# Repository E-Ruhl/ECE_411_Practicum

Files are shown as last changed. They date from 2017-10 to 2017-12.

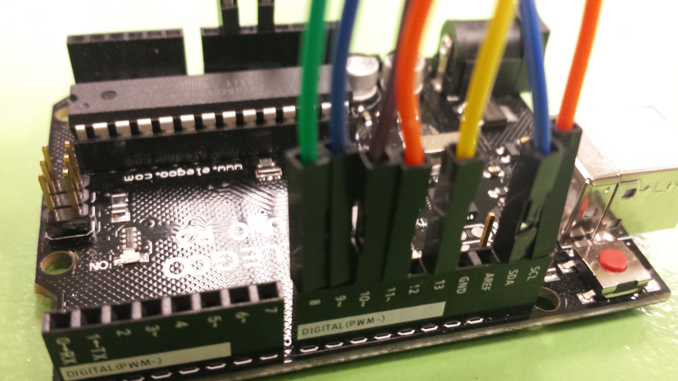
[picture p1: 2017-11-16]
Photo Documentation/Prototype Board Wiring.jpg

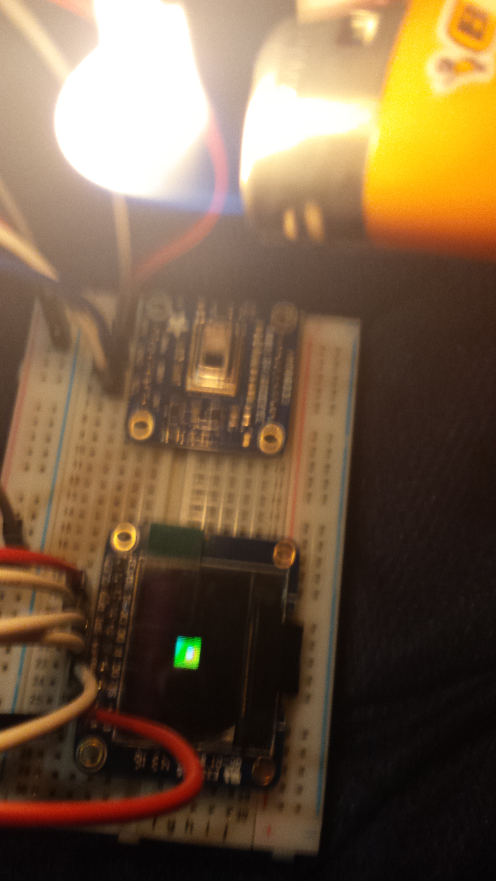
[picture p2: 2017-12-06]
Photo Documentation/Testing_Prototype.jpg

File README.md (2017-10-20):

# ECE_411_Practicum
Project development

Check out these sites for getting an idea of what we might try

https://www.adafruit.com/product/3538
this is the IR Camera

https://www.adafruit.com/product/684
this is the OLED screen

http://www.microchip.com/wwwproducts/en/ATmega328
this is the microcontroller

http://www.instructables.com/id/Arduino-Data-Glasses-for-My-Multimeter/
This is an instructable for a DIY Heads up display that actually has decent documentation

https://www.autodesk.com/education/free-software/eagle#
You'll need to go here to download the educational version of Eagle Cad

Also because I got super excited and already ordered most of the material for the thermal overlay augmented reality HUD, if you're into that idea (because I'm eventually doing it either way) then read up on Bicubic interpolation!!!

Other programs you might want to consider
Jupyter Notebook- Allows you to use basic Latex markdown and run python in an online application.

https://wwwspikenzielabs.com/Catalog/index.php?main_page=product_infor&products_id=614

We'll set up meeting notes on friday.

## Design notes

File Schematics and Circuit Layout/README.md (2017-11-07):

Folder containing all the information related to the schematics needed to build the Thermal Imaging HUD

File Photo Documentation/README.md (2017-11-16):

This is where the various project photos are stored. The photo documentation was taken from 1st prototype to final production.

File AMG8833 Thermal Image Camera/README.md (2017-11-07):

Folder containing all information related to the AMG8833 Thermal Image Camera

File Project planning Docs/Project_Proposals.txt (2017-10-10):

"Bucket of Options"

1. Light-up frisbee
2. Talking ball
3. Pasive aggressive condiment robot
4. Thermal overlay augmented reality hub
5. Visual distance to audio converter (Vision impared assistant device)
6. Chat bot
7. Kegorator
8. LED tesseract
9. Path finder robot
10. Amature band jammer

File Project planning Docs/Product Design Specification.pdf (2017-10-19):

# Thermal Imaging HUD

Eric Ruhl
Preston Cazier
Kirk Hooper
Dustin Schnelle

Version 1.1 10/17/17

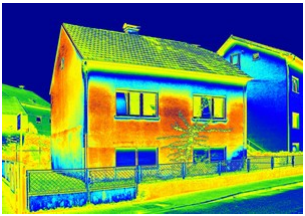
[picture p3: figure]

### Table of Contents

Product Proposal | Page 3-4
Product Description | Page 3
Requirements | Page 4
Deliverables | Page 4
Product Design Specifications | Page 5-6
Needs | Page 5
Objectives | Page 5
Background | Page 5
Marketing Requirements | Page 5
Constraints | Page 6
Engineering Requirements | Page 6
Functionality | Page 6
Performance | Page 6
Economic | Page 6
Energy | Page 6
Environmental | Page 6
Health and Safety | Page 6
Legal | Page 6
Maintainability | Page 6
Manufacturability | Page 6
Operational | Page 6
Political | Page 6
Reliability and Availability | Page 6
Social and Cultural | Page 6
Usability | Page 6

### Project Proposal

Project Description:
Our team is going to build a thermal imaging device. Our device will use a sensor to obtain a thermal image of the environment and an actuator to display the thermal image. Then we will use lenses to create a virtual image of the thermal image. The device should be able to take a thermal image produced by the sensor and then increase the resolution of the image before being displayed to the actuator.

Our first idea is to create a thermal image using a thermal imaging camera. The thermal imaging camera will transmit the data to a processor where it will preform the task of increasing the resolution of the image before displaying it to an LED display. We want the design to be compact, so it can be worn by the user in the form of glasses. At this point we are still trying to figure out the exact method that we need to use in order to increase the resolution of the image without requiring too much storage space.

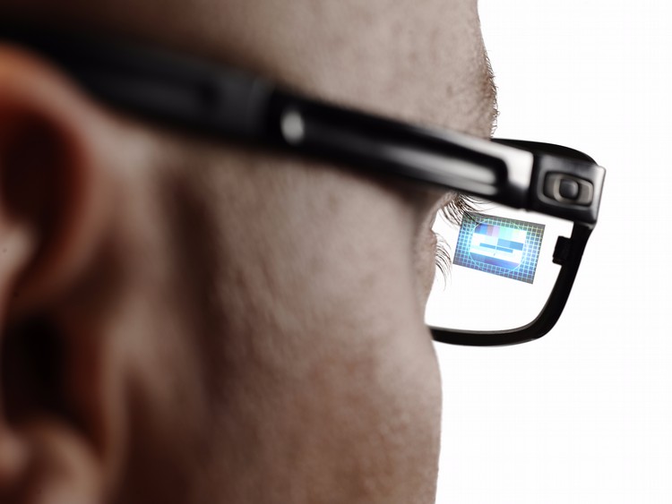
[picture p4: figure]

Image #1: Example of the virtual image display

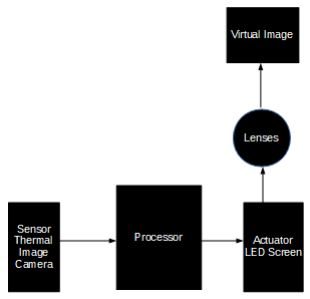
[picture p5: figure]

Image #2: Basic dataflow of the Thermal Imaging HUD

Requirements:
- The device must be able to product a real-time thermal image of the environment.
- The device must be compact enough, so that it can be worn in the form of glasses.
- The resolution must be clear enough to analyze the thermal image.

Deliverables:
- One working prototype of a thermal imaging HUD.

### Product Design Specifications

Needs:
Our team has decided to create a device that will display thermal images in real-time for our ECE-411 practicum project. In order to produce a thermal image we will use a thermal imaging camera. Thermal imaging cameras are devices that translate thermal energy into images that can be displayed and analyzed. Thermal imaging technology is currently being used by the military, firefighters, law enforcement, and technicians to name just a few. As most thermal imaging technology costs upwards of $500 our groups' mission is to try to create a thermal imaging device that will be low cost compared to what's currently on the market. This device would be useful for anyone that wants to build a thermal imaging device on a budget. It could be used for fun or tackling problems that involve thermal energy. We believe that we will be successful because of our teams' various engineering backgrounds. Ideally, this project will help us achieve a good grade in this class, look great on a resume and allow us to gain valuable team project development skills. Although we are taking on the risk of failing the class if unsuccessful. The cost will be affordable for a student and be able to be completed in one term (~ 10 weeks). Obtaining a working prototype with a thermal camera, OLED screen, and microprocessor will be our “midterm” and a fully functional final project will be our “final” for the class.

Objectives:
Our objective is to create a thermal imaging device using a thermal imaging camera and screen to display the thermal image. This will be a hands-free device that will display the thermal image to the user of the device as a virtual image. The device will receive input from a thermal camera produced by a thermal image. The thermal image will be processed by the processor in order to increase the resolution of the image and then be outputted to a screen. The screen will produce the image in order for glass lenses to create a virtual image. The device will be portable and compact so the user can wear them as glasses.

Background:
All of the other similar products on the market are more expensive; costing upwards of $500. Many of the devices are expensive because they're used in situations that require extreme reliability. Our device won't require that kind of reliability which allows for the device to be less expensive. This allows for our device to be used by hobbyist on a budget.

Marketing Requirements:
- The device should be compact enough so it can be worn as glasses.
- The device should process the thermal image fast enough to produce a video feed.
- The device should respond to the environment and changes in the environment.
- The device should be cheap to build.
- The device shouldn't cause harm to the user.
- The device should be simple to use.

Constraints:
- Must have at least one input sensor.
- Must have at least one output actuator.
- Must have some kind of digital or analog processor.
- Must have the microprocessor located on the PCB.
- Must be able to fit on a two-layer PCB.
- Must have documentation and use version control.
- Must be published with MIT license.

Engineering Requirements:
Functionality
The device need to refresh an image at a minimum of 10 Hz.
The image need to be viewable from a heads-up lens that is 1 sq. inch. Performance
The thermal images need to be recognizable from the heads-up display. Economic
Total parts cost will not exceed $200.
Energy
The device should be able to operate from a battery for at least 2 hours. Environmental
At least 50% of the devices modular components will be able to be replaced. Health and Safety
The device shouldn't become hotter than 75o
F.
Legal
The project will use a MIT license.
Maintain 10 Hz or less for the thermal camera (export requirement). Maintainability
Both the actuator and sensor should be easily replaceable on daughter boards. Manufacturability
PCB should be greater than 2 sq. inches and less than 20 sq. inches.
All the casing for the project will be commercially source-able.
Operational
The device needs to weigh between 1 lb and 5 lbs.
The device should be no more than 100 sq. inches total.
Reliability and Availability
The device should be able to detect thermal images between 1 ft to 20 ft. Usability
The device can be used in a mobile capacity.

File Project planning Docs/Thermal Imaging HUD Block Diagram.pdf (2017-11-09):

## Thermal Imaging HUD

## Block Diagram

Dustin Schnelle
Eric Rulh
Preston Cazier
Kirk Hooper

Table of Content:

Thermal Imaging HUD: Level 0 | Page 3
Thermal Imaging HUD: Level 1 | Page 4
Over Charge Protection: Level 0 | Page 5
LiPo Battery: Level 0 | Page 6
Brown Out/Over Discharge Protection: Level 0 | Page 7
3.3V Linear Regulation: Level 0 | Page 8
3.3V Linear Regulator: Level 0 | Page 9
Noise Reduction: Level 0 | Page 10
Oscillator: Level 0 | Page 11
Microcontroller: Level 0 | Page 12
AMG8833 Thermal Imaging Camera: Level 0 | Page 13
AMG8833 Thermal Imaging Camera: Level 1 | Page 14
Panasonic Infrared Sensor Array: Level 0 | Page 15
Linear Voltage Regulator AMG8833: Level 0 | Page 16
Level Shifting: Level 0 | Page 17
SSD1331 OLED Display: Level 0 | Page 18
SSD1331 OLED Display: Level 1 | Page 19
Linear Voltage Regulator SSD1331: Level 0 | Page 20
Non-Inverting High-to-Low Level Shifter: Level 0 | Page 21
OLED LCD Display: Level 0 | Page 22

Thermal Imaging HUD: Level 0

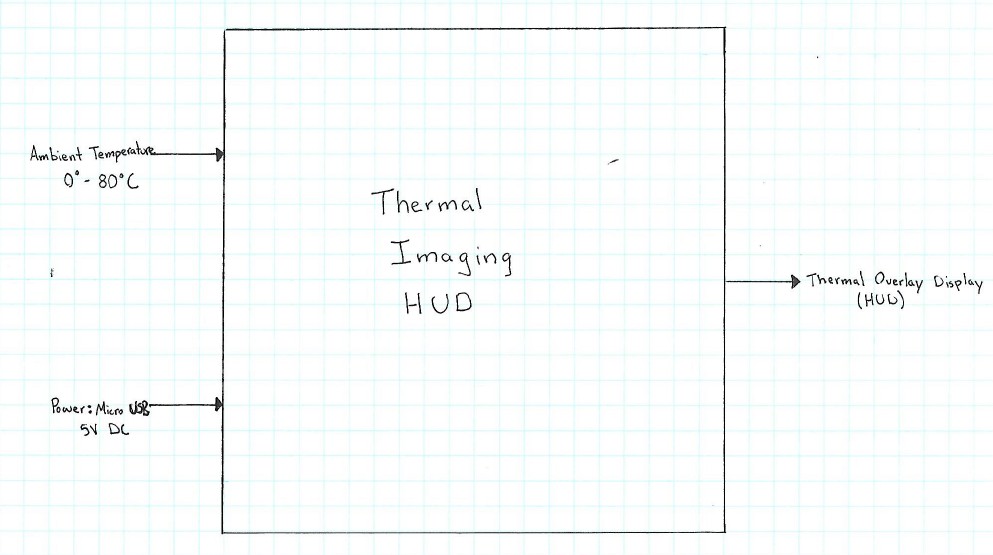
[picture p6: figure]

Module | Thermal Imaging HUD
Inputs | • Ambient temperature between 0o – 80oC • Power: Micro-USB 5V DC
Outputs | • Thermal Overlay Displays (HUD)
Functionality | Measure a matrix of ambient temperature between 0o – 80oC with an accuracy of +/-2.5oC. Then process the ambient temperature data and transmit via I2C communication. The microcontroller executes an image processing algorithm to extrapolate to a large more displayable matrix. Then transfer the data via SPI communication to the OLED display. The image is then optically transmitted through a glass lenses to the heads up display.

Thermal Imaging HUD: Level 1

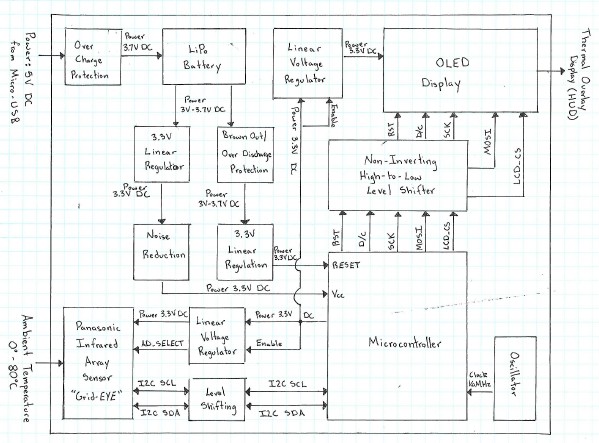
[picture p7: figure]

Over Charge Protection: Level 0

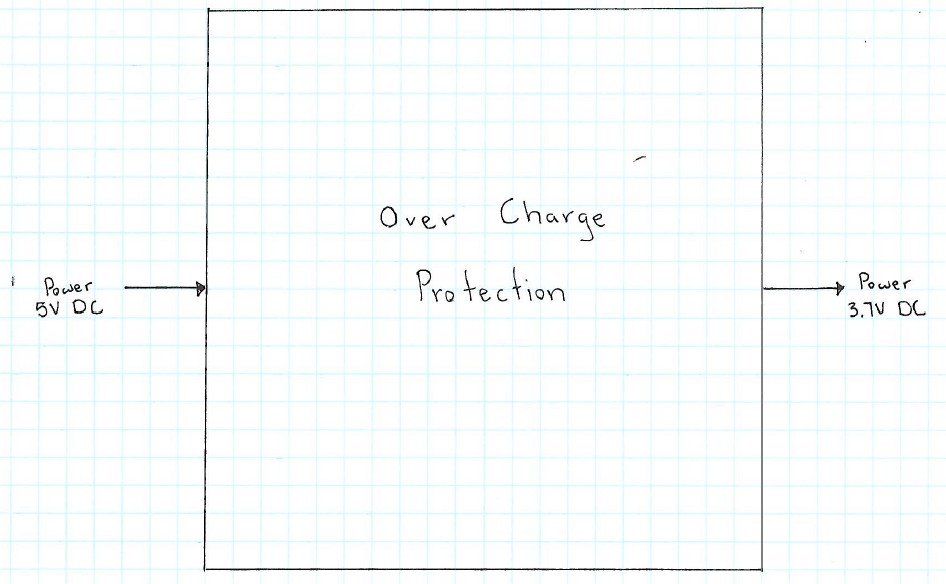
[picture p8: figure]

Module | Over Charge Protection
Inputs | • Power: 5V DC from the micro-USB
Outputs | • Power: 3.7V DC
Functionality | To prevent the LiPo battery from charging more than 3.7V DC. Prevent the explosion/damage of the LiPo battery.

LiPo Battery: Level 0

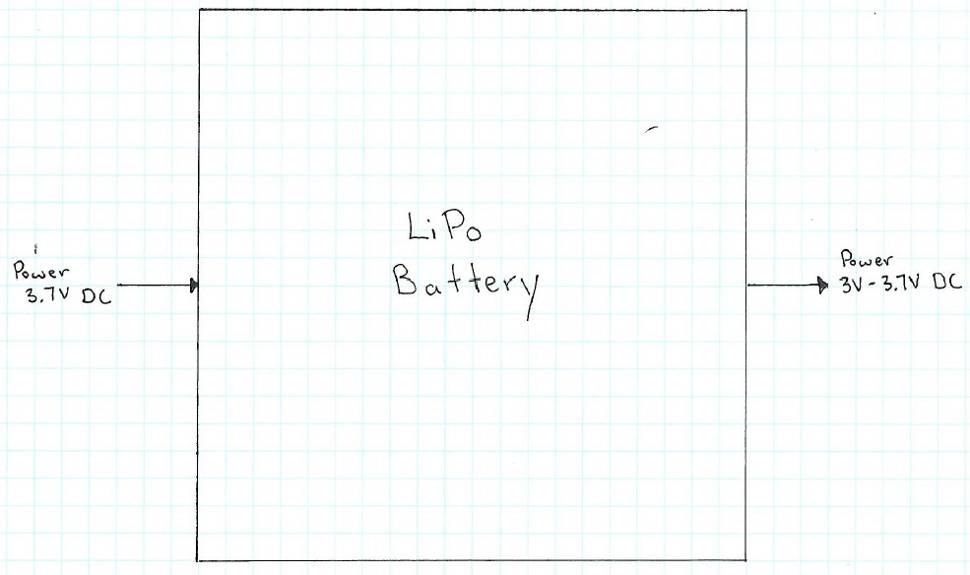
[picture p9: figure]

Module | LiPo Battery
Inputs | • Power: 3.7V DC from the over charge protection
Outputs | • Power: 3V – 3.7V DC
Functionality | To provide portable power to the circuit

Brown Out/Over Discharge Protection: Level 0

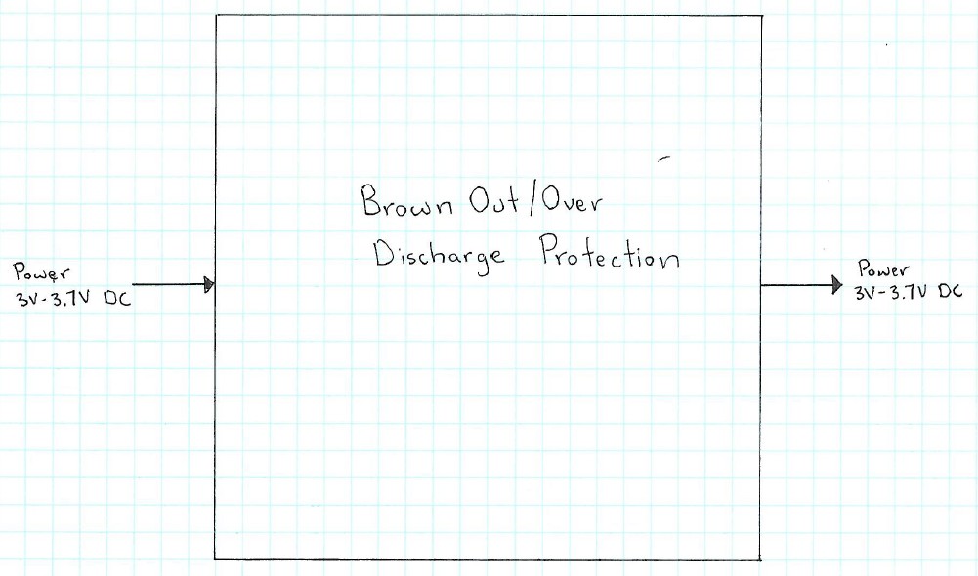
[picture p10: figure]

Module | Brown Out/Over Discharge Protection
Inputs | • Power: 3V – 3.7V DC from the LiPo battery
Outputs | • Power: 3V – 3.7V DC with undercurrent protection
Functionality | To protect the LiOp battery form over discharging.

3.3V Linear Regulation: Level 0

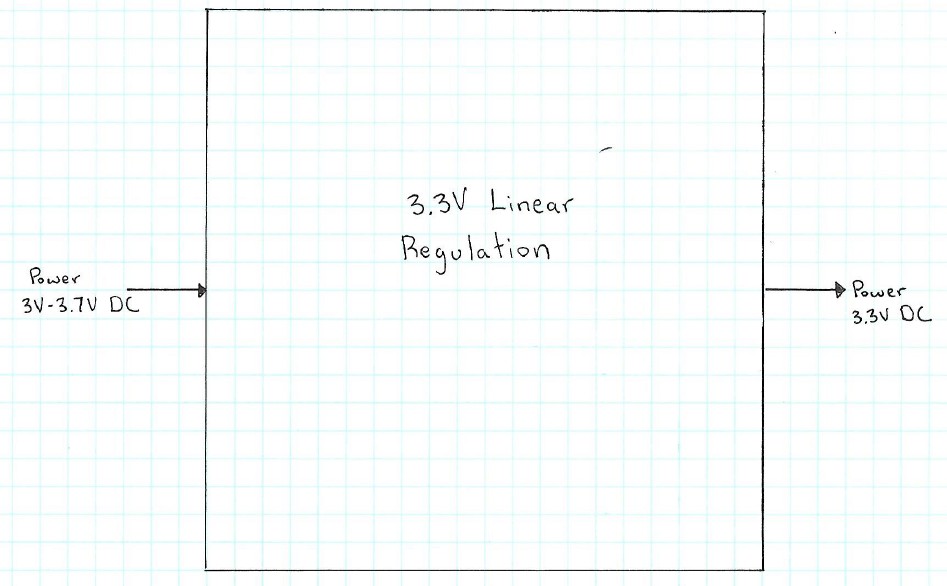
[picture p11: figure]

Module | 3.3V Linear Regulation
Inputs | • Power: 3V – 3.7V DC from LiPo battery through the brown out/over discharge protection.
Outputs | • Power: 3.3V DC
Functionality | Takes the voltage provided by the LiPo battery to provide a 3.3V DC Reset logic of the mircocontroller.

3.3V Linear Regulator: Level 0

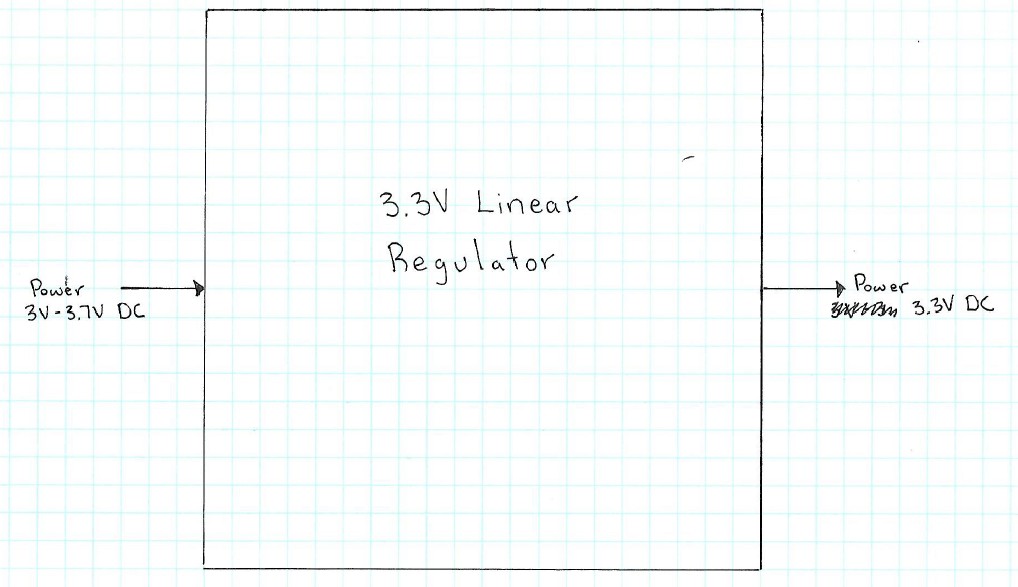
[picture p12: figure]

Module | 3.3V Linear Regulator
Inputs | • Power: 3V – 3.7V DC from the LiPo battery
Outputs | • Power: 3.3V DC
Functionality | Takes the voltage provided by the LiPo battery to provide a 3.3V DC Vcc for the mircocontroller.

Noise Reduction: Level 0

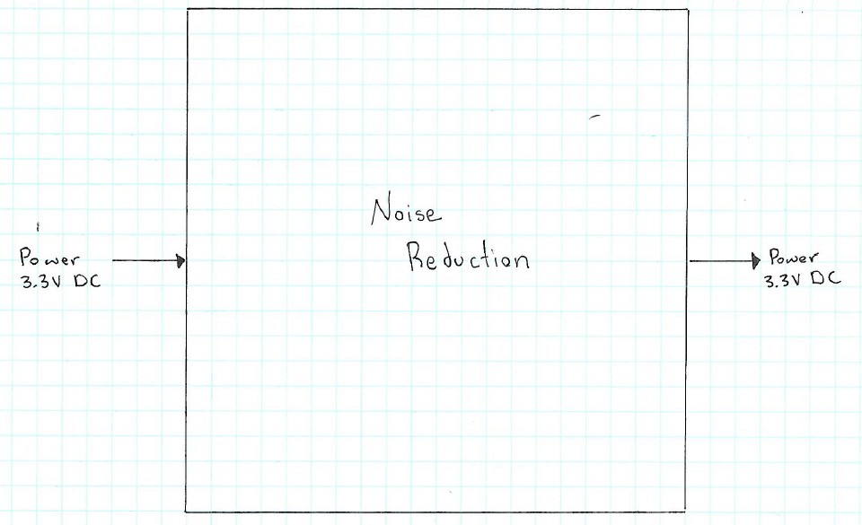
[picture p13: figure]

Module | Noise Reduction
Inputs | • Power: 3.3V DC from the voltage regulator
Outputs | • Power: 3.3V DC less noise
Functionality | Reducing electric noise from the ground plan using ferrite beads

Oscillator: Level 0

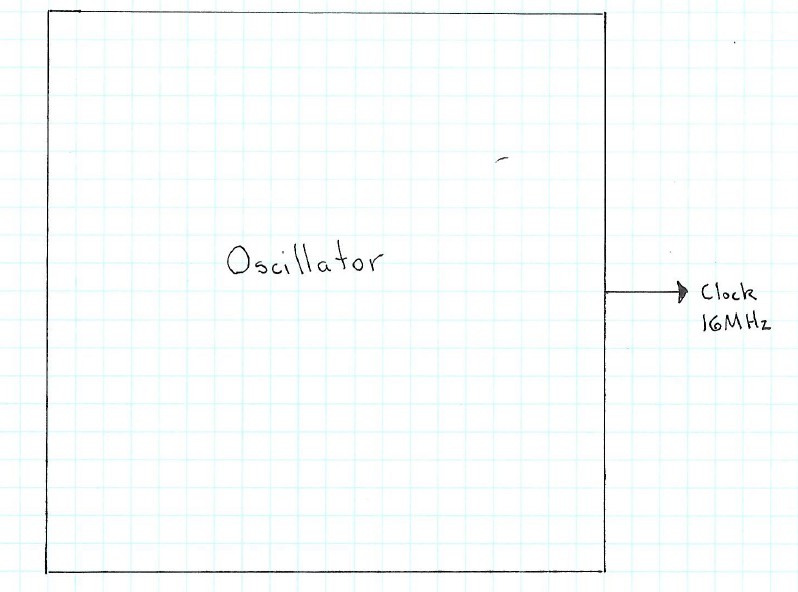
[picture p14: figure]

Module | Oscillator
Inputs | • None
Outputs | • Clock: 16MHz
Functionality | Sends the mircocontroller a 16MHz clock pulse.

Microcontroller: Level 0

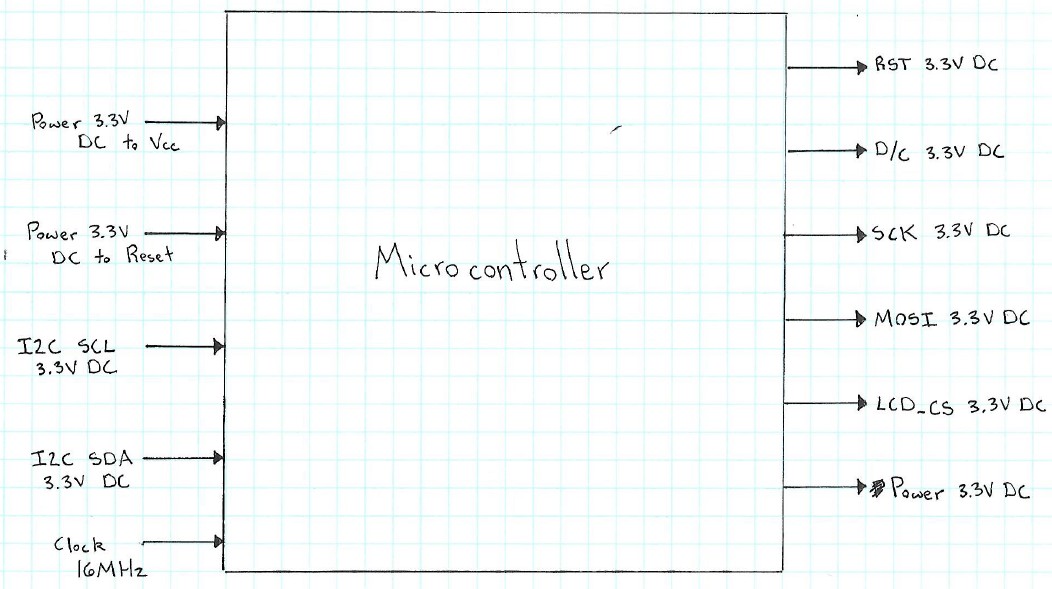
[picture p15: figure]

Module | Microcontroller
Inputs | • Power: 3.3V DC to Vcc and AVcc • Power: 3.3V DC to reset and once the voltage falls below 3.3V reset becomes active • I2C SCL: I2C serial clock line 3.3V DC bidirectional communication • I2C SDA: I2C serial data line 3.3V DC bidirectional communication • Clock: 16Mhz
Outputs | • Power: 3.3V DC • RST: 3.3V DC signal used to reset OLED display • D/C: 3.3V DC • SCK: 3.3V DC SPI clock line • MOSI: 3.3V DC SPI master out/slave in • LCD_CS: 3.3V DC signal to select the OLED display
Functionality | Translate the I2C data to SPI output data with an intermediate step of extrapolating the input 8x8 image matrix to a larger output image matrix.

AMG8833 Infrared Thermal Imaging Camera: Level 0

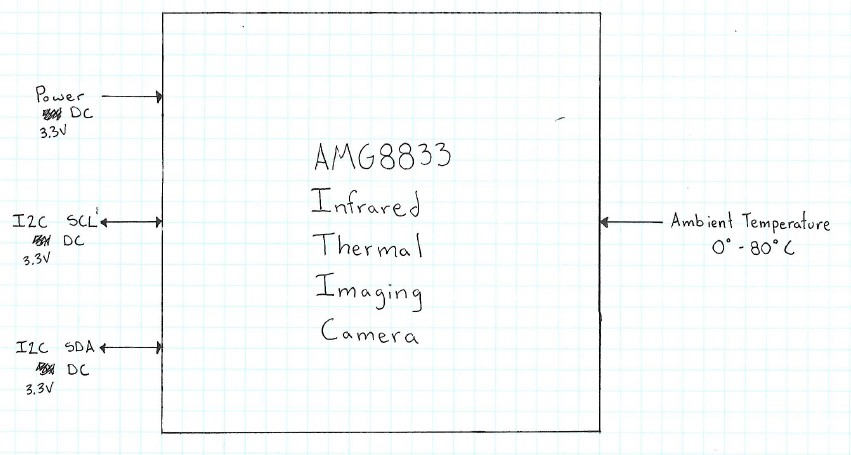
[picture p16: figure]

Module | AMG8833
Inputs | • Ambient temperature from 0o to 80oC • I2C SCL: to receive master requests • I2C SDA: to receive master requests • Power: 3.3V DC
Outputs | • I2C SCL: to transmit ambient temperature to master • I2C SDA: to transmit ambient temperature to master
Functionality | Return an array of 64 (8x8) individual infrared temperature readings with an accuracy of +/- 2.5oC via I2C when requested by master device.

AMG8833 Infrared Thermal Imaging Camera: Level 1

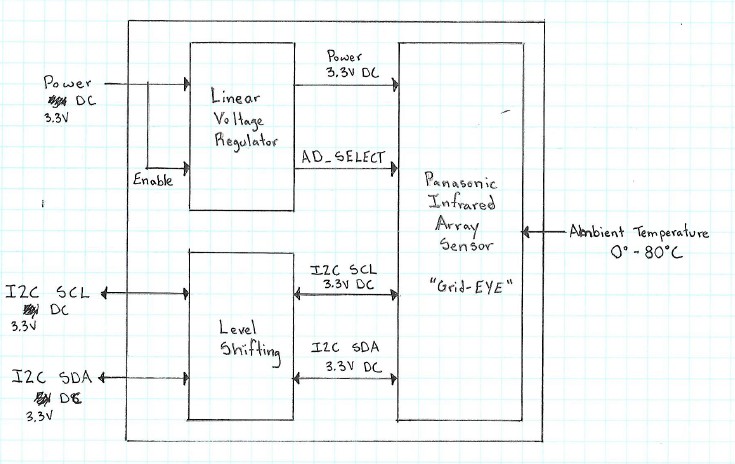
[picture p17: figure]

Panasonic Infrared Array Sensor: Level 0

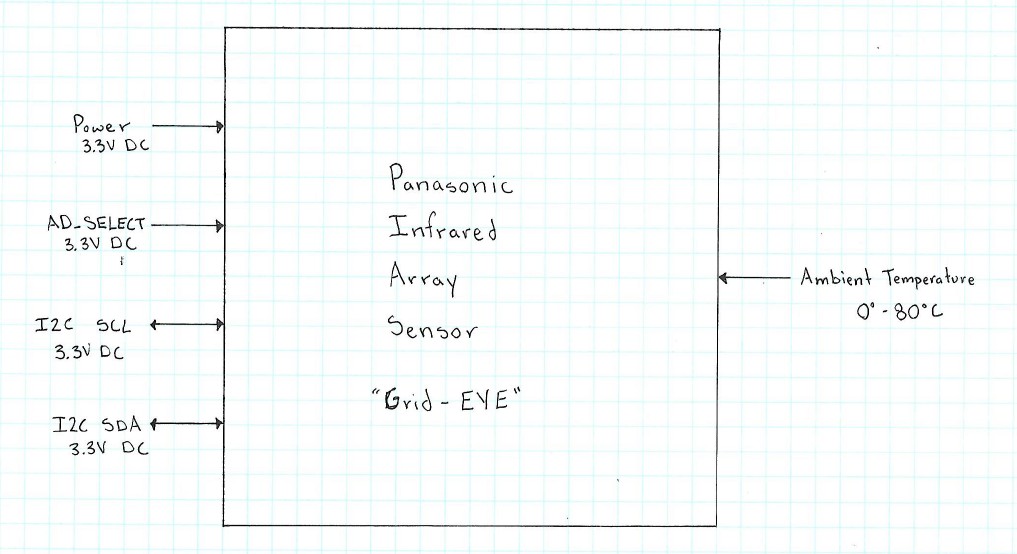
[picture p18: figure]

Module | Panasonic Infrared Array Sensor “Grid-EYE”
Inputs | • Ambient temperature from 0o to 80oC • I2C SCL: 3.3V DC • I2C SDA 3.3V DC • AD_SELECT: configurable slave address of the device • Power: 3.3V DC
Outputs | • I2C SCL: 3.3V DC • I2C SDA: 3.3V DC
Functionality | Return an array of 64 (8x8) individual infrared temperature readings via I2C when requested by master device. Control registers can be programmed by the master.

Linear Voltage Regulator AMG8833: Level 0

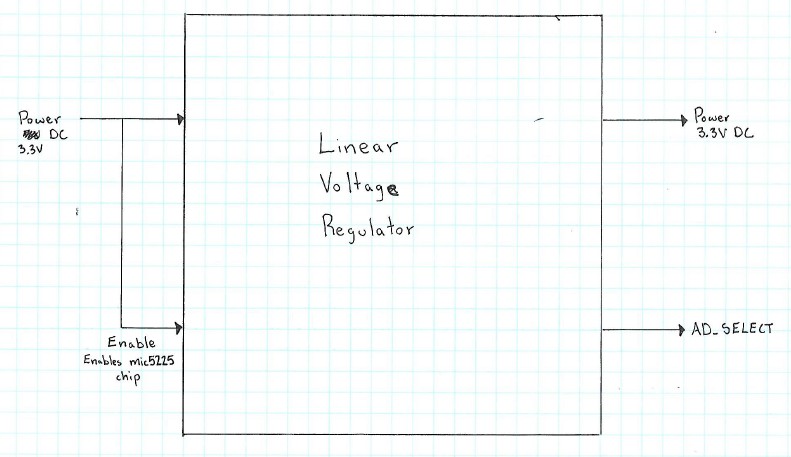
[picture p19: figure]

Module | Linear Voltage Regulator
Inputs | • Power: 3.3V DC • Enable: to enable the mic5225-3.3V chip (tied to power)
Outputs | • Power: 3.3V DC • AD_SELECT: configurable slave address of the device
Functionality | Regulated power supply that produces 3.3V DC using the mic5225-3.3V chip and an input voltage of 3.3V DC.

Level Shifting: Level 0

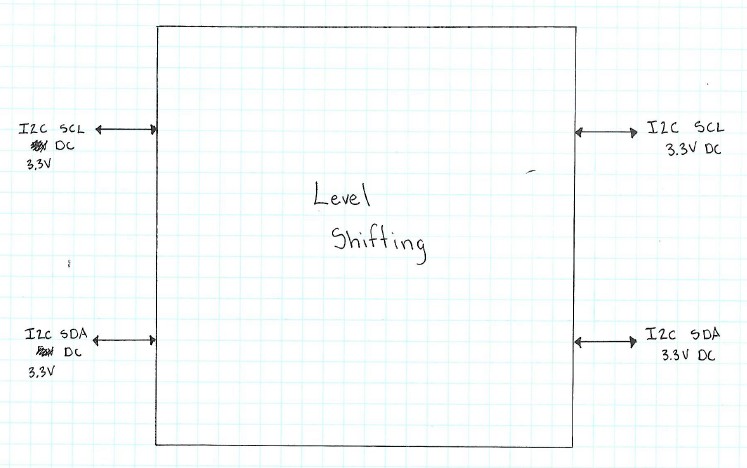
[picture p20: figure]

Module | Level Shifting
Inputs | • Power: 3.3V DC I2C SCL signal • Power: 3.3V DC I2C SDA signal
Outputs | • Power: 3.3 DC I2C SCL signal • Power: 3.3 DC I2C SDA signal
Functionality | Shifts the voltage level of the I2C communication signal form 3.3V DC to 3.3V DC using two BSS138 MOSEFTs.

SSD1331 OLED Display: Level 0

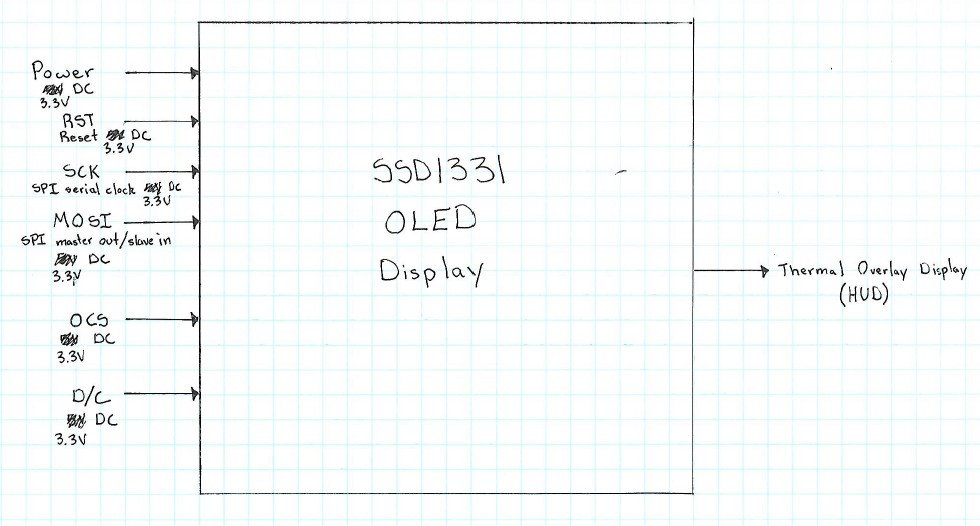
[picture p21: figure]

Module | SSD1331 OLED display
Inputs | • RST: Reset • SCK: SPI serial clock • MOSI: SPI master out/slave in • OCS: OLED chip select • D/C: Data command controll • Power: 3.3V DC
Outputs | • Display the array of individual ambient temperature in with colors to represent the temperature of the current pixel.
Functionality | Displays the transformed ambient temperature array of 64 individual pixels data to OLED display via SPI communication from the processor.

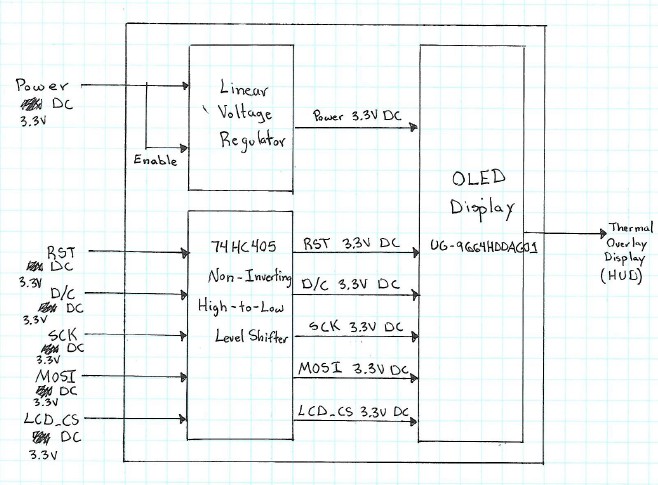
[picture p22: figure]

SSD1331 OLED Display: Level 1

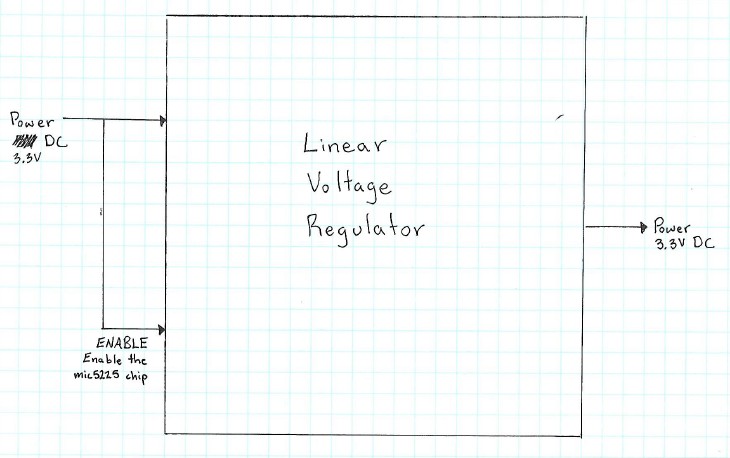
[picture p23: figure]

Linear Voltage Regulator SSD1331: Level 0

Module | Linear Voltage Regulator
Inputs | • Power: 3.3V DC • Enable: to enable the mic5225-3.3V chip (tied to power)
Outputs | • Power: 3.3V DC
Functionality | Regulated power supply that produces 3.3V DC using the mic5225-3.3V chip and an input voltage of 3.3V DC.

Non-Inverting High-to-Low Level Shifter: Level 0

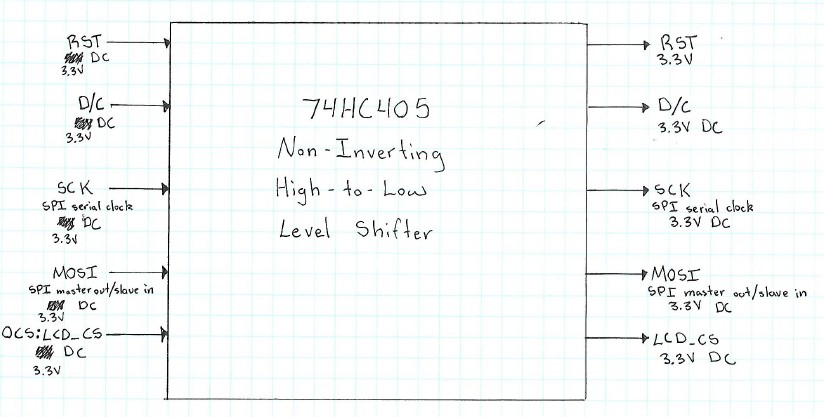
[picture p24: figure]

Module | 74HC4050 Non-Inverting High-to-Low Level Shifter
Inputs | • RST: reset 3.3V DC • SCK: SPI serial clock 3.3V DC • MOSI: SPI master out/slave in 3.3V DC • LCD_CS: OLED chip select 3.3V DC • DC: Data command control 3,3V DC
Outputs | • RST: reset 3.3V DC • SCK: SPI serial clock 3.3V DC • MOSI: SPI master out/slave in 3.3V DC • LCD_CS: OLED Chip select 3.3V DC • DC: Data command control 3.3V DC
Functionality | Shifts the voltage levels of the inputs from high voltage (3.3V DC) to low voltage (3.3V DC).

OLED LCD Display: Level 0

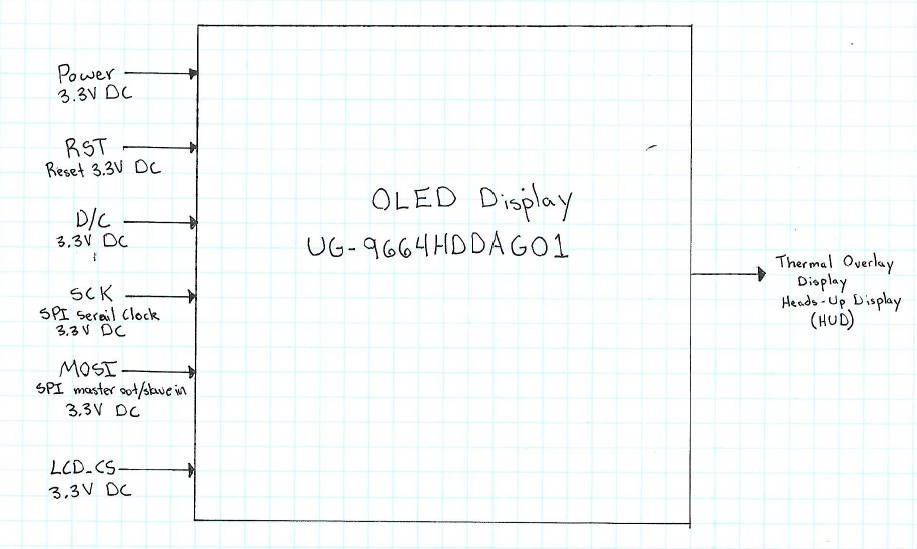
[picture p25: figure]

Module | OLED Display UG-9664HDDAG01
Inputs | • RST: reset 3.3V DC • SCK: SPI serial clock 3.3V DC • MOSI: SPI master out/slave in 3.3V DC • LCD_CS: OLED Chip select 3.3V DC • DC: Data command control 3.3V DC • Power: 3.3V DC
Outputs | • Thermal Overlay Display HUD
Functionality | Displays the transformed thermal imaging data to the OLED Display. The image is then propagated through the mirror to the HUD.

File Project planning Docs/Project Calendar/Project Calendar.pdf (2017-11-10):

ID | Task Name | Duration | Start | Finish | Predecessors
1 | Product development process | 7 days | Mon 10/9/17 | Tue 10/17/17
2 | Develop practicum project ideas | 1 day | Mon 10/9/17 | Mon 10/9/17
3 | Setup Wiki for the pacticum project | 1 day | Thu 10/12/17 | Thu 10/12/17
4 | Complete preliminary system design | 1 day | Tue 10/17/17 | Tue 10/17/17
5 | Develop project proposal | 2 days | Fri 10/13/17 | Mon 10/16/17
6 | Research project background | 1 day | Fri 10/13/17 | Fri 10/13/17
7 | Write draft of project background/proposal | 1 day | Fri 10/13/17 | Fri 10/13/17
8 | Review draft of project background/proposal | 1 day | Sat 10/14/17 | Sat 10/14/17
9 | Revise draft of project background/proposal | 2 days | Sat 10/14/17 | Mon 10/16/17
10 | Review revised project background/proposal | 1 day | Mon 10/16/17 | Mon 10/16/17
11 | Approve project background/proposal | 1 day | Mon 10/16/17 | Mon 10/16/17
12 | Develop project requirements document | 2 days | Mon 10/16/17 | Tue 10/17/17
13 | Write draft of engineering requirements | 1 day | Mon 10/16/17 | Mon 10/16/17
14 | Write draft of marketing requirments | 1 day | Mon 10/16/17 | Mon 10/16/17
15 | Revise engineering requirements | 1 day | Mon 10/16/17 | Mon 10/16/17
16 | Revise marketing requirements | 1 day | Mon 10/16/17 | Mon 10/16/17
17 | Link engineering and marketing requirements | 1 day | Tue 10/17/17 | Tue 10/17/17
18 | Approve project requirements document | 1 day | Tue 10/17/17 | Tue 10/17/17
19 | Complete preliminary schematic | 4 days | Sun 10/22/17 | Wed 10/25/17 | 1
20 | Determine what needs to be included on fabricated board 3 days | Sun 10/22/17 | Tue 10/24/17
21 | Create the preliminary schematic | 1 day | Tue 10/24/17 | Tue 10/24/17
22 | Review preliminary schematic | 1 day | Wed 10/25/17 | Wed 10/25/17

Eric,Preston,Kirk,Dustin

S | M | T | W

Oct 8, '17

Task

Split

Milestone

Summary

Project Summary

Inactive Task

Inactive Milestone

Inactive Summary

Manual Task

Duration-only

Manual Summary Rollup

Manual Summary

Start-only

Finish-only

External Tasks

External Milestone

Deadline

Baseline

Baseline Milestone

Baseline Summary

Progress

Manual Progress

Project: Project Calendar
Date: Fri 11/10/17

ID | Task Name | Duration | Start | Finish | Predecessors
23 | Approve preliminary schematic | 1 day | Wed 10/25/17 | Wed 10/25/17
24 | Complelete final schematic | 2 days | Fri 10/27/17 | Sun 10/29/17 | 19
25 | Design test points and indicator lights | 1 day | Fri 10/27/17 | Fri 10/27/17
26 | Create final schematic | 1 day | Fri 10/27/17 | Fri 10/27/17
27 | Review final schematic | 1 day | Sun 10/29/17 | Sun 10/29/17
28 | Approve final schematic | 1 day | Sun 10/29/17 | Sun 10/29/17
29 | Complelete design layout | 4 days | Wed 11/1/17 | Sat 11/4/17 | 24
30 | Create priliminary layout | 1 day | Wed 11/1/17 | Wed 11/1/17
31 | Review priliminary layout | 1 day | Wed 11/1/17 | Wed 11/1/17
32 | Create final layout | 2 days | Thu 11/2/17 | Fri 11/3/17
33 | Review final layout | 1 day | Fri 11/3/17 | Fri 11/3/17
34 | Revise final layout | 1 day | Sat 11/4/17 | Sat 11/4/17
35 | Approve final layout | 1 day | Sat 11/4/17 | Sat 11/4/17
36 | Develop detailed system design | 2 days | Fri 11/3/17 | Sat 11/4/17
37 | Draw high level block diagram | 1 day | Fri 11/3/17 | Fri 11/3/17
38 | Review high level block diagram | 1 day | Fri 11/3/17 | Fri 11/3/17
39 | Draw next-level block diagram | 1 day | Fri 11/3/17 | Fri 11/3/17
40 | Review next-level block diagram | 1 day | Fri 11/3/17 | Fri 11/3/17
41 | Create top-level block diagram of each module in next-level block diagram | 1 day | Sat 11/4/17 | Sat 11/4/17
42 | Review top-level block diagram | 1 day | Sat 11/4/17 | Sat 11/4/17
43 | Revise the detailed system design | 1 day | Sat 11/4/17 | Sat 11/4/17
44 | Approve detailed systrm design | 1 day | Sat 11/4/17 | Sat 11/4/17
S | M | T | W

Oct 8, '17

Task

Split

Milestone

Summary

Project Summary

Inactive Task

Inactive Milestone

Inactive Summary

Manual Task

Duration-only

Manual Summary Rollup

Manual Summary

Start-only

Finish-only

External Tasks

External Milestone

Deadline

Baseline

Baseline Milestone

Baseline Summary

Progress

Manual Progress

Project: Project Calendar
Date: Fri 11/10/17

ID | Task Name | Duration | Start | Finish | Predecessors
45 | Test/Debug practicum project | 3 days | Wed 11/29/17 | Fri 12/1/17 | 75
46 | Create detailed test case | 1 day | Wed 11/29/17 | Wed 11/29/17
47 | Complete design measurements | 1 day | Wed 11/29/17 | Wed 11/29/17
48 | Measure the heads-up display | 1 day | Wed 11/29/17 | Wed 11/29/17
49 | Measure the PCB against specifications | 1 day | Wed 11/29/17 | Wed 11/29/17
50 | Weigh the final design against specifications | 1 day | Wed 11/29/17 | Wed 11/29/17
51 | Test refresh rate and heads-up display for functionability | 1 day | Fri 12/1/17 | Fri 12/1/17
52 | Test device over a range of temperatures | 1 day | Fri 12/1/17 | Fri 12/1/17
53 | Test battery capacity for 2 hours | 1 day | Fri 12/1/17 | Fri 12/1/17
54 | Test thermal imaging between range of 1ft to 20ft | 1 day | Fri 12/1/17 | Fri 12/1/17
55 | Present practicum project | 2 days | Sat 12/2/17 | Sun 12/3/17 | 45
56 | Develop fully working prototype | 1 day | Sat 12/2/17 | Sat 12/2/17
57 | Develop a power point presentation | 2 days | Sat 12/2/17 | Sun 12/3/17
58 | Practice presentation | 1 day | Sun 12/3/17 | Sun 12/3/17
59 | AVR programming | 2 days | Fri 11/3/17 | Sat 11/4/17
60 | Coding through Arduino controller | 2 days | Fri 11/3/17 | Sat 11/4/17
61 | Coding with the circuit | 1 day | Sat 11/4/17 | Sat 11/4/17
62 | Build ISPC using QTFP adapter | 1 day | Sat 11/4/17 | Sat 11/4/17
63 | Design battery supply | 2 days | Tue 10/24/17 | Wed 10/25/17
64 | Determine type of power supply to use | 1 day | Tue 10/24/17 | Tue 10/24/17
65 | Develop protections | 1 day | Tue 10/24/17 | Tue 10/24/17
66 | Implement the design in the circuit | 2 days | Tue 10/24/17 | Wed 10/25/17
S | M | T | W

Oct 8, '17

Task

Split

Milestone

Summary

Project Summary

Inactive Task

Inactive Milestone

Inactive Summary

Manual Task

Duration-only

Manual Summary Rollup

Manual Summary

Start-only

Finish-only

External Tasks

External Milestone

Deadline

Baseline

Baseline Milestone

Baseline Summary

Progress

Manual Progress

Project: Project Calendar
Date: Fri 11/10/17

ID | Task Name | Duration | Start | Finish | Predecessors
67 | Develop physical casings | 4 days | Mon 11/20/17 | Thu 11/23/17 | 75
68 | Measure the casing | 1 day | Mon 11/20/17 | Mon 11/20/17
69 | Create OBJ files | 1 day | Mon 11/20/17 | Mon 11/20/17
70 | 3D print the casing | 2 days | Wed 11/22/17 | Thu 11/23/17
71 | Coding design | 3 days | Thu 10/19/17 | Sat 10/21/17 | 1
72 | Review OLED screen library | 1 day | Thu 10/19/17 | Thu 10/19/17
73 | Review thermal imaging camera library | 1 day | Thu 10/19/17 | Thu 10/19/17
74 | Review processor manual | 2 days | Fri 10/20/17 | Sat 10/21/17
75 | Develop optics for the heads-up display | 5 days | Mon 11/13/17 | Fri 11/17/17
76 | Create test stand | 1 day | Mon 11/13/17 | Mon 11/13/17
77 | Measure alignment | 1 day | Mon 11/13/17 | Mon 11/13/17
78 | Create final structure | 5 days | Mon 11/13/17 | Fri 11/17/17
79 | Develop and manufacture a test sturcture | 1 day | Fri 11/17/17 | Fri 11/17/17

80

S | M | T | W

Oct 8, '17

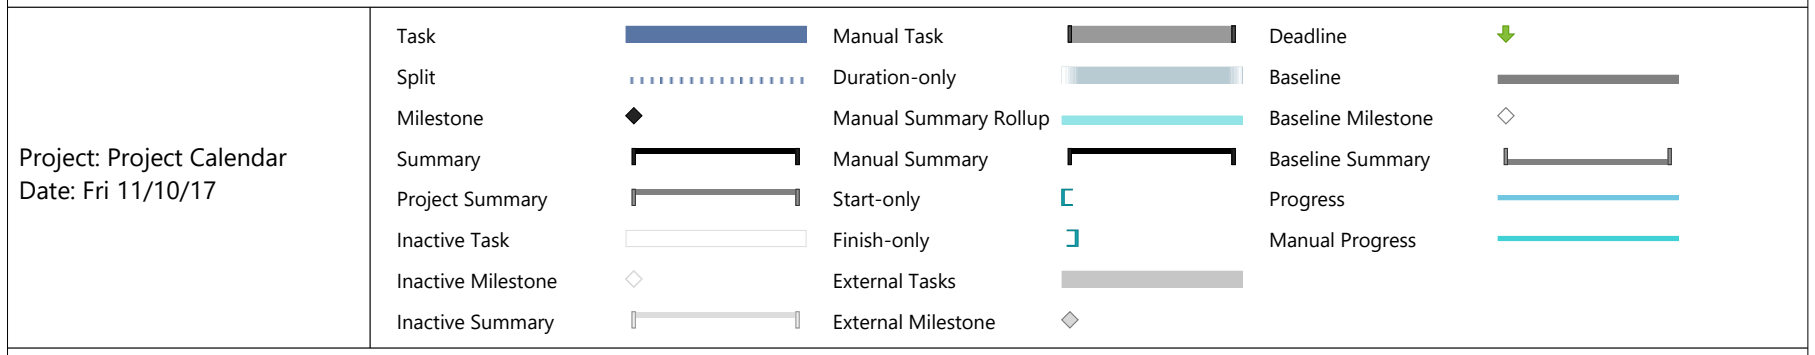
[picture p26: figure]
Task; Split; Milestone; Summary; Project Summary; Inactive Task; Inactive Milestone; Inactive Summary; Manual Task; Duration-only; Manual Summary Rollup; Manual Summary; Start-only; Finish-only; External Tasks; External Milestone; Deadline; Baseline; Baseline Milestone; Baseline Summary; Progress; Manual Progress; Project: Project Calendar Date: Fri 11/10/17

Eric,Preston,Kirk,Dustin; Eric; Preston,Dustin; Eric,Kirk; Oct 15, '17; Oct 22, '17; Oct 29, '17; Nov 5, '17; Nov 12, '17; Task; Split; Milestone; Summary; Project Summary; Inactive Task; Inactive Milestone; Inactive Summary; Manual Task; Duration-only; Manual Summary Rollup; Manual Summary; Start-only; Finish-only; External Tasks; External Milestone; Deadline; Baseline; Baseline Milestone; Baseline Summary; Progress; Manual Progress; Project: Project Calendar Date: Fri 11/10/17

Eric,Preston,Kirk,Dustin; Eric; Preston,Eric; Kirk,Dustin; Kirk,Dustin,Eric,Preston; Oct 15, '17; Oct 22, '17; Oct 29, '17; Nov 5, '17; Nov 12, '17; Task; Split; Milestone; Summary; Project Summary; Inactive Task; Inactive Milestone; Inactive Summary; Manual Task; Duration-only; Manual Summary Rollup; Manual Summary; Start-only; Finish-only; External Tasks; External Milestone; Deadline; Baseline; Baseline Milestone; Baseline Summary; Progress; Manual Progress; Project: Project Calendar Date: Fri 11/10/17

Preston,Kirk,Dustin; Eric; Oct 15, '17; Oct 22, '17; Oct 29, '17; Nov 5, '17; Nov 12, '17; Task; Split; Milestone; Summary; Project Summary; Inactive Task; Inactive Milestone; Inactive Summary; Manual Task; Duration-only; Manual Summary Rollup; Manual Summary; Start-only; Finish-only; External Tasks; External Milestone; Deadline; Baseline; Baseline Milestone; Baseline Summary; Progress; Manual Progress; Project: Project Calendar Date: Fri 11/10/17

Kirk
Dustin
Kirk,Dustin
T | F | S | S | M | T | W | T | F | S | S | M | T | W | T | F | S | S | M | T | W | T | F | S | S | M | T | W | T | F | S | S
Oct 15, '17 | Oct 22, '17 | Oct 29, '17 | Nov 5, '17 | Nov 12, '17

Nov 12, '17; Nov 19, '17; Nov 26, '17; Dec 3, '17; Dec 10, '17; Task; Split; Milestone; Summary; Project Summary; Inactive Task; Inactive Milestone; Inactive Summary; Manual Task; Duration-only; Manual Summary Rollup; Manual Summary; Start-only; Finish-only; External Tasks; External Milestone; Deadline; Baseline; Baseline Milestone; Baseline Summary; Progress; Manual Progress; Project: Project Calendar Date: Fri 11/10/17

Kirk,Dustin,Eric,Preston; Nov 12, '17; Nov 19, '17; Nov 26, '17; Dec 3, '17; Dec 10, '17; Task; Split; Milestone; Summary; Project Summary; Inactive Task; Inactive Milestone; Inactive Summary; Manual Task; Duration-only; Manual Summary Rollup; Manual Summary; Start-only; Finish-only; External Tasks; External Milestone; Deadline; Baseline; Baseline Milestone; Baseline Summary; Progress; Manual Progress; Project: Project Calendar Date: Fri 11/10/17

Preston; Eric

M | T | W | T | F | S | S | M | T | W | T | F | S | S | M | T | W | T | F | S | S | M | T | W | T | F | S | S | M | T | W | T
Nov 12, '17 | Nov 19, '17 | Nov 26, '17 | Dec 3, '17 | Dec 10, '17

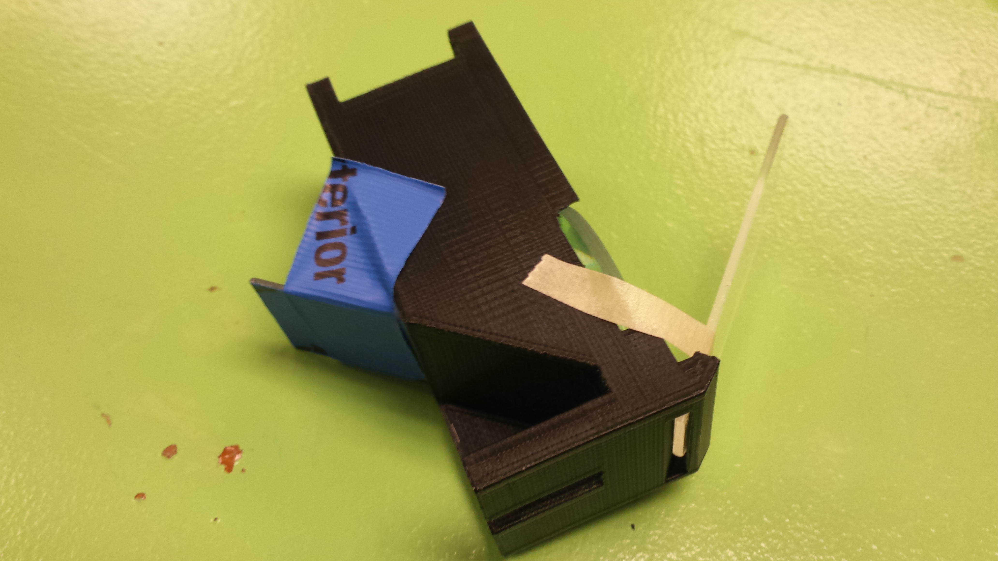
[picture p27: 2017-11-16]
Photo Documentation/Casing Prototype 2.jpg

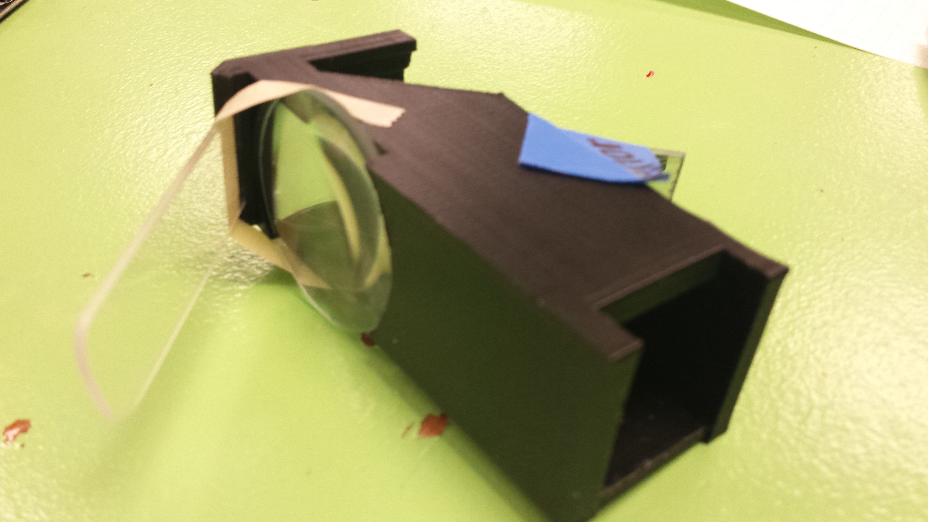
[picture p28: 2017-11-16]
Photo Documentation/Casing Prototype 1.jpg

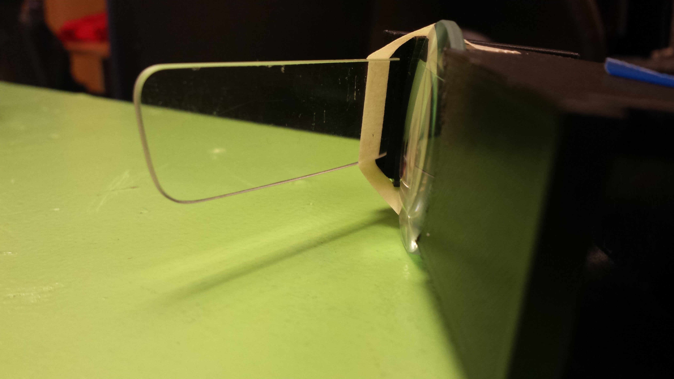
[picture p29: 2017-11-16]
Photo Documentation/Casing Prototype 5.jpg

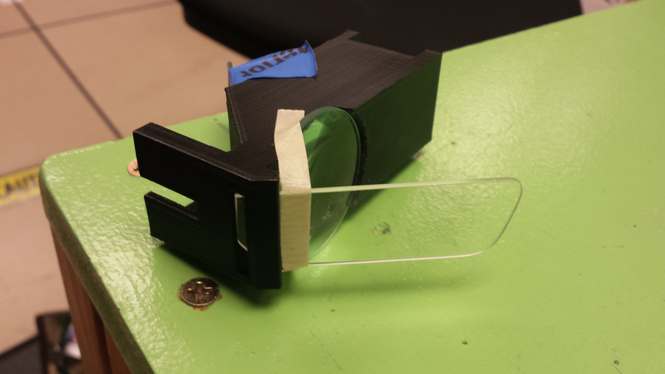
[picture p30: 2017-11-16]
Photo Documentation/Casing Prototype 3.jpg

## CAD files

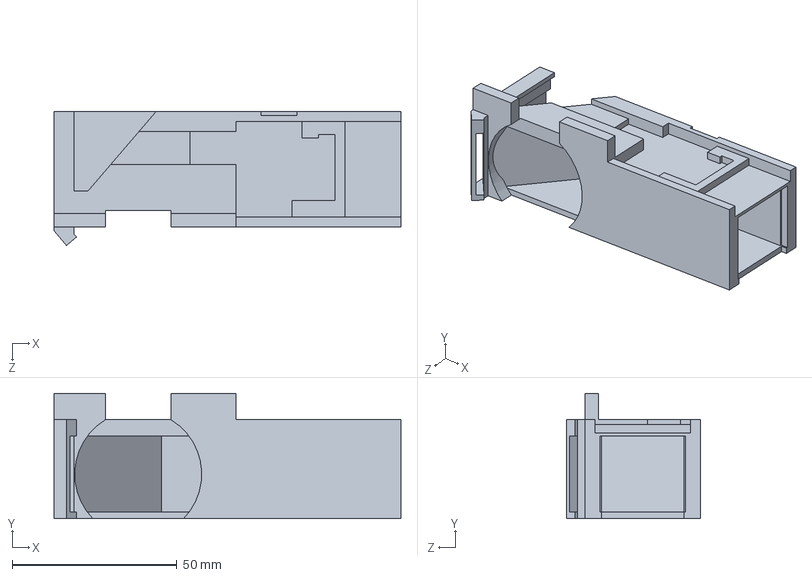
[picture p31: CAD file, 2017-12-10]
Structrual files/optical body_v1.3.SLDPRT
105.2 x 38.0 x 40.6 mm

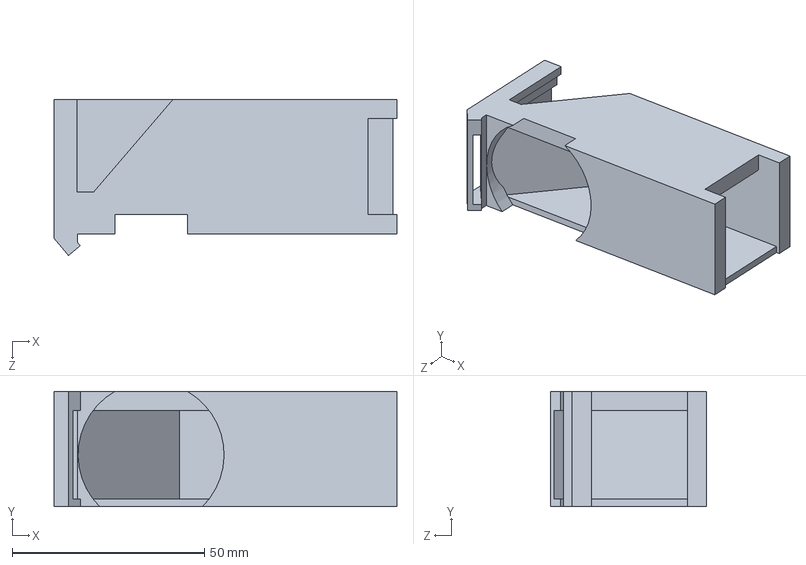
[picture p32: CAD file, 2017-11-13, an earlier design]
Structrual files/optical body.SLDPRT
89.3 x 30.0 x 40.6 mm

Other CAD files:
Structrual files/optical body_v1.2.SLDPRT
Structrual files/optical body.STL
Structrual files/optical body_v1.2.STL
Structrual files/optical body_v1.3.STL

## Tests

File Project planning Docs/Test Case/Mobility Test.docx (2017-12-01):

Test Writer | | Eric Ruhl
Test Case Name | | Mobility | | | | | Test ID | FP_00
Description | | Long term continuous use | | | | | Type | Black Box | X
| | | | | | | | White Box

Test Information
Name of Tester | | | | | | | Date
Relevant Version # | | | | | | | Time
Setup | | Attach the optical apparatus to some form of wearable structure.
Additional Equipment | | Wearable structure
Stage | Operation | | Expectation | P | F | / | Comment
1 | Don the apparatus | | It will stay on your head
2 | Go about your business | | There are no notable points of discomfort
3 | Remove apparatus | | There are no visible marks left behind by the device
Overall Results

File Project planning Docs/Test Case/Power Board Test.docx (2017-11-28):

Test Writer | | Eric Ruhl
Test Case Name | | Charge Circuit | | | | | Test ID | MB-1
Description | | Measure Power input cutoff regions to battery from micro USB | | | | | Type | Black Box | X
| | | | | | | | White Box

Test Information
Name of Tester | | | | | | | Date
Relevant Version # | | | | | | | Time
Setup | | With the switch in the ON position, plug the micro USB adapter into the micro USB port on the power board. Set the power supply to output 5 volts and set the current limit to 10 mA. While the power supply is in current view mode, connect the power supply to the leads of the micro USB adapter, and slowly bring the current limit up. Attach the multi-meter leads to the capacitor.
Additional Equipment | | Voltage Controlled, Current limited Power supply Multi-meter Bare Wire to Micro USB adapter 100 nF Capacitor with battery port connector
Stage | Operation | | Expectation | P | F | / | Comment
1 | Look at the multi-meter | | There will be a non-zero voltage reading
2 | Wait | | The chip will not be smoking
3 | Look at the multi-meter | | The voltage reading has gone up slightly
Overall Results

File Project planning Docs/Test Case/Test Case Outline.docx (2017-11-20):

Test Writer
Test Case Name | | | | | | | Test ID
Description | | | | | | | Type | Black Box
| | | | | | | | White Box

Test Information
Name of Tester | | | | | | | Date
Hardware Version | | | | | | | Time
Setup
Additional Equipment
Stage | Operation | | Expectation | P | F | / | Comment
Overall Results

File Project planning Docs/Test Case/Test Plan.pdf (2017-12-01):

Thermal | Imaging | HUD

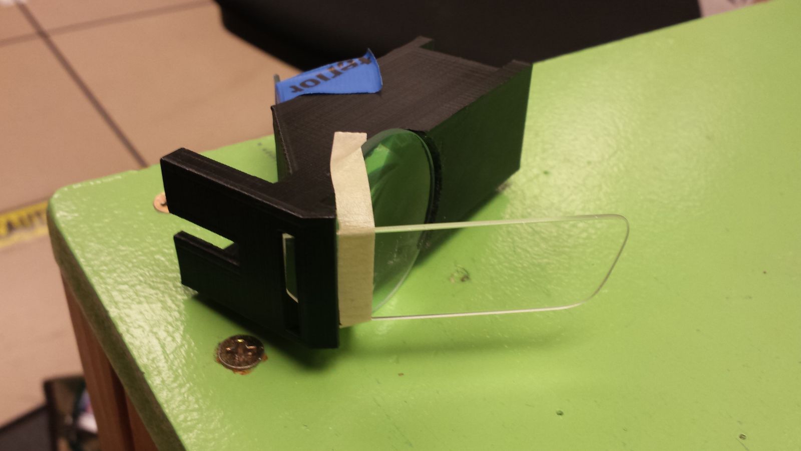
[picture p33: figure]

Authors:
Preston Crazier
Kirk Hooper
Eric Ruhl
Dustin Schnelle
Revision: | 0.1 | Date: | November 29, 2017

Document | History | and | Distribution
Revision | History:
Revision | Changes | Date
0.1 | Initial draft | 11/29/2017

Table | of | Contents
1. | Introduction | 4
1.1 Objective | 4
1.2 Scope | 4
1.3 Testing Strategy | 4
1.4 Reference Material | 4
1.5 Definitions and Acronyms | 5
2. | Test | Items | 5
2.1 Equipment | 5
3. | Features | to | be | Tested | 5
4. | Features | not | to | be | Tested | 6
5. | Approach | 6
5.1 Test Setup | 6
5.2 Component Testing | 6
5.3 Integration Testing | 7
5.4 Completed test cases | 8

## 1. Introduction

The Thermal Imaging HUD project is a low cost IR thermal camera device designed to output the environments’ thermal temperature to a heads-up-display (HUD). This thermal imaging device is hands free, allowing the user to interact with their environment while still being able to perform complex hands-on tasks. The device continuously reads the ambient temperature of its environment using a IR thermal imaging camera so the user can see real-time temperature data using an OLED display. Problems relating to the environments’ ambient temperature can then be observed, trouble-shot, diagnosed and possibly even prevented. This test plan was created to enable the developers of the Thermal Imaging HUD project to quickly and efficiently bring the prototype PCB up to full functionality.

### 1.1 Objective

This test plan outlines the testing process and also defines each of the individual test cases that will be used to ensure a fully functional prototype is designed. The tests conducted are to be consistent with the Product Design Specification, Revision 1.1, dated 10/17/2017.

### 1.2 Scope

The objective of this test plan is to safely and efficiently power up the Thermal Imaging HUD prototype board, so that the thermal imaging camera, OLED display, microprocessor and image processing technique can be verified to be operating as expected. The microprocessor will be powered-up and the daughterboards connected (thermal imaging camera and OLED display) onto the prototype board. The software will then be tested in the range of ambient temperatures. The accuracy of the Thermal Imaging HUD’s display will be tested against known ambient temperatures to ensure that it meets project specifications. For this version of the test plan the main objective is to have a working prototype consisting of a single board to be demonstrated at 4:30pm on Wednesday, December 6

th

### 1.3 Testing Strategy

The general strategy for testing is going to be following sequential paths. For circuit testing, this is the current pathway, from where power is put into our board, then following it through essentially in the order current travels through the traces. For structural testing, there is also an order off testing that nicely follows the order of assembly.

### 1.4 Reference Material

- Thermal Imaging HUD Product Design Specification, Reversion 1.1
- Thermal Imaging HUD Schematic, Reversion 1.1

- Thermal Imaging HUD PCB Layout, Reversion 1.1
- AMG8833 Schematic, Reversion B
- AMG8833 PCB Layout, Reversion B
- Adafruit 94x64 RGB OLED Schematic, Reversion B
- Adafruit 94x64 RGB OLED PCB Layout, Reversion B
- Thermal Imaging HUD Block Diagram

### 1.5 Definitions and Acronyms

- HUD: Heads-up Display
- PCB: Printed Circuit Board
- OLED: Organic Light-Emitting Diode
- IR: Infrared
- EPL: Electronic Prototype Lab
- PW: Power system testing ID
- CM: IR thermal camera testing ID
- OD: OLED display testing ID
- FP: Final Prototype testing ID

## 2. Test Items

### 2.1 Equipment

- Power Supply
- Digital Multimeter
- Object for temperature testing
- Human (Recognize body temperature)
- Wall (Ambient temperature of a room)
- Ice Cube (Lower temperature range)
- Lighter (Higher temperature range)
- IR laser thermometer

## 3. Features to be Tested

- Wearability of the HUD device
- Mobility of the HUD device
- Battery power supply
- Battery operation time
- OLED screen isolated functionality
- OLED screen functionality integrated with the prototype
- IR thermal camera isolated functionality

- IR thermal camera functionality integrated with the prototype
- Temperature reading accuracy
- Distance reading accuracy

## 4. Features not to be Tested

- Operation temperature boundary conditions
- Refresh rate of the OLED screen
- Image alignment of the display

## 5. Approach

Listed below are each of the test cases with their associated test case IDs. Completed test cases will be included below with generic versions of each test case.

### 5.1 Test Setup

Most of the necessary test and measurement equipment are available in the EPL. Items need to generate tests for the various temperature ranges (ice, lighter, and IR laser thermometer) will be brought into the EPL by team Thermal Imaging HUD members.

### 5.2 Component Testing

- Power supply test (ID# PW_00)
- Isolated IR thermal camera test (ID# CM_00)
- Isolated OLED display test (ID# OD_00)
- Battery operation test (ID# PW_01)
Functionality | of | each | component | test:
Power | supply | test: | Test the the ability of the power supply unit to charge a LiPo battery. Then
test the functionality of the reset bin under operation. Lastly test the voltage of the supply pins on the board.
Isolated | IR | thermal | camera | test: | Test the basic functionality of the IR thermal camera
connected to the microprocessor. This test isolates the IR thermal camera daughter board from the rest of the circuit to make sure it operates as expected before integration.
Isolated | OLED | display: | Test the basic functionality of the OLED display connected to the
microprocessor. This test isolates the OLED display daughter board from the rest of the circuit to make sure it operates as expected before integration.
Battery | operation | test: | Test that the operation of circuit with a charged battery to make sure
the device functions as expected.

### 5.3 Integration Testing

- IR camera thermal camera sensor test (ID# CM_01)
- OLED display actuator test (ID# OD_01)
- Wearability/Mobility device test (ID# FP_00)
- IR temperature sensor range test (ID# CM_02)
- IR temperature sensor distance test (ID# CM_03)
Functionality | of | each | integration | test:
IR | camera | thermal | camera | sensor | test: | Test the basic functionality of the IR camera thermal
camera sensor once integrated with the final prototype.
OLED | display | actuator | test: | Test the basic functionality of the OLED display actuator once
integrated with the final prototype.
Wearability/Mobility | device | test: | Test the comfortability of wearing the device for long periods
of time. Also make sure the device is compact enough to be comfortable when being warn by the user.
IR | temperature | sensor | range | test: | Test the accuracy of the measured temperature range of
the device. This test will require a live human body, a wall in a room, a ice cube, and a lighter for the various temperatures under test.
IR | temperature | sensor | distance | test: | Test the accuracy of objects at a distance of the
measured temperature of the device. This test will require live human body at various distances from the device.

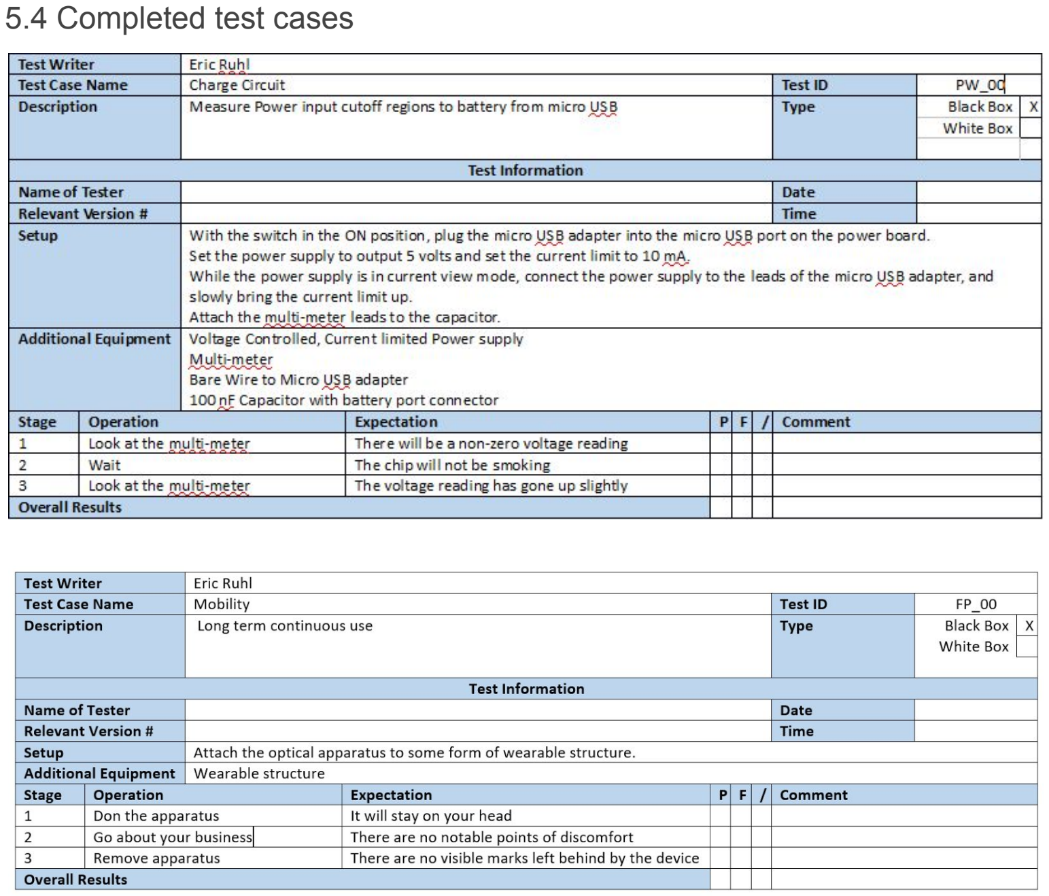
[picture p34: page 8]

### 5.4 Completed test cases

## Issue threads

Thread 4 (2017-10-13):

Image Processing and Storage

E-Ruhl, 2017-10-13:
Determine method for parts of images to be stored on external SD card or to up the perceived output of the microcontroller

E-Ruhl, 2017-10-15:
Current assessment of method for image processing is that with 10 Hz, we can just reprocess for every batch of pixels we need to send and still be fine in terms of camera refresh rate.

Closed 2017-12-06.

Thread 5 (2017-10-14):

Order Correct lenses

E-Ruhl, 2017-10-14:
Lenses that came in original order where not correct

Closed 2017-10-15.

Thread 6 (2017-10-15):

Order Battery

E-Ruhl, 2017-10-15:
Need a way to power the device, and a way to regulate the power.

E-Ruhl, 2017-10-15:
I've Purchased 2 3.7 volt lipol batteries, as well as a metric crap ton of voltage regulators.

Closed 2017-10-15.

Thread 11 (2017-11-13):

Add ICSP connection to the board design

schnelled, 2017-11-13:
We need to add an ICSP connection to the board to be able to program the ATMEGA328. There is currently no way to program the chip.

schnelled, 2017-11-17:
ICSP connection added to the board

Closed 2017-11-17.

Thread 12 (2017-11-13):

Major Issues with PCB design

schnelled, 2017-11-13:
1. LED2 won't do what we intend it to do. STAT is an open collector and it only pulls to ground.
2. Resolve ERC warnings.
3. Add team number and project name to the schematic.

Closed 2017-11-17.

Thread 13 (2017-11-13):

Critical Layout Errors

schnelled, 2017-11-13:
Add team number and board revision to silkscreen.

schnelled, 2017-11-17:
Team number and board revisions added to silkscreen.

Closed 2017-11-17.

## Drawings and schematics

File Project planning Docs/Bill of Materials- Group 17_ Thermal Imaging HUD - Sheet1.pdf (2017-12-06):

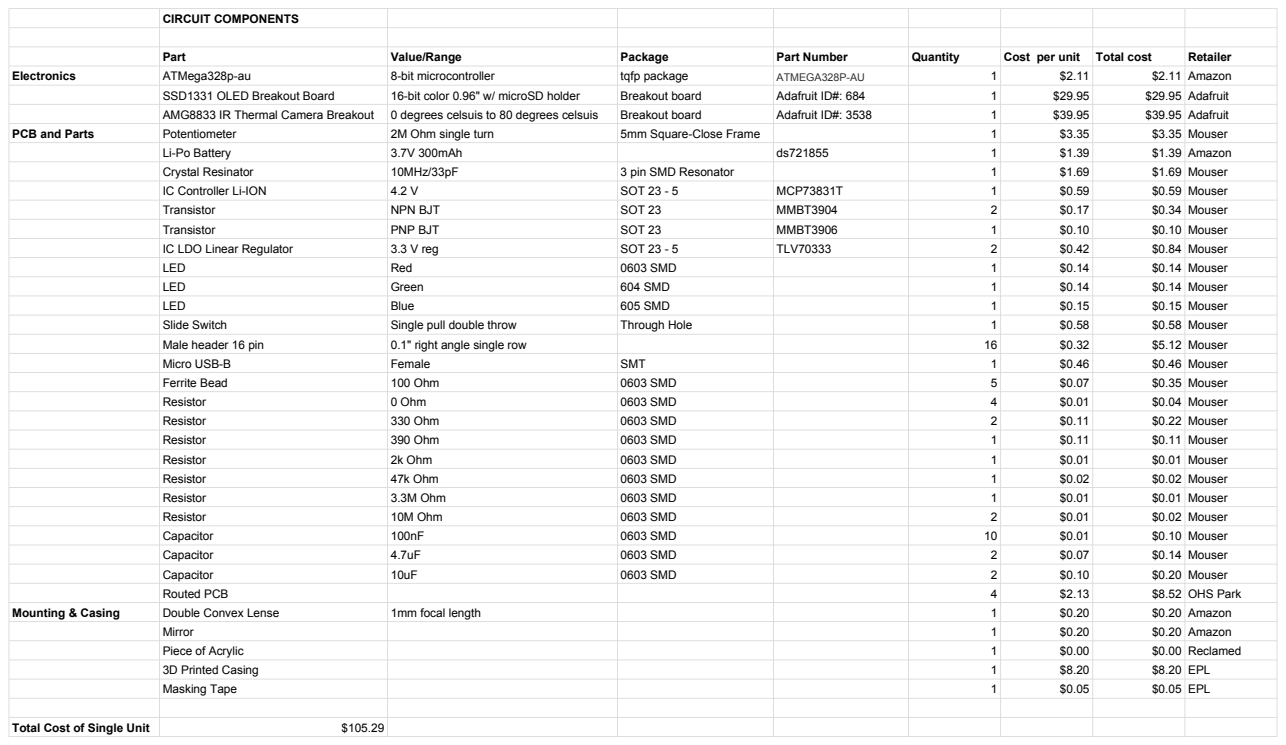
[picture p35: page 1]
CIRCUIT COMPONENTS; Part; Value/Range; Package; Part Number; Quantity; Cost per unit; Total cost; Retailer; Electronics; ATMega328p-au; 8-bit microcontroller; tqfp package; ATMEGA328P-AU; $2.11 Amazon; SSD1331 OLED Breakout Board; 16-bit color 0.96" w/ microSD holder; Breakout board; Adafruit ID#: 684; $29.95 Adafruit; AMG8833 IR Thermal Camera Breakout; 0 degrees celsuis to 80 degrees celsuis; Adafruit ID#: 3538; $39.95 Adafruit; PCB and Parts; Potentiometer; 2M Ohm single turn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

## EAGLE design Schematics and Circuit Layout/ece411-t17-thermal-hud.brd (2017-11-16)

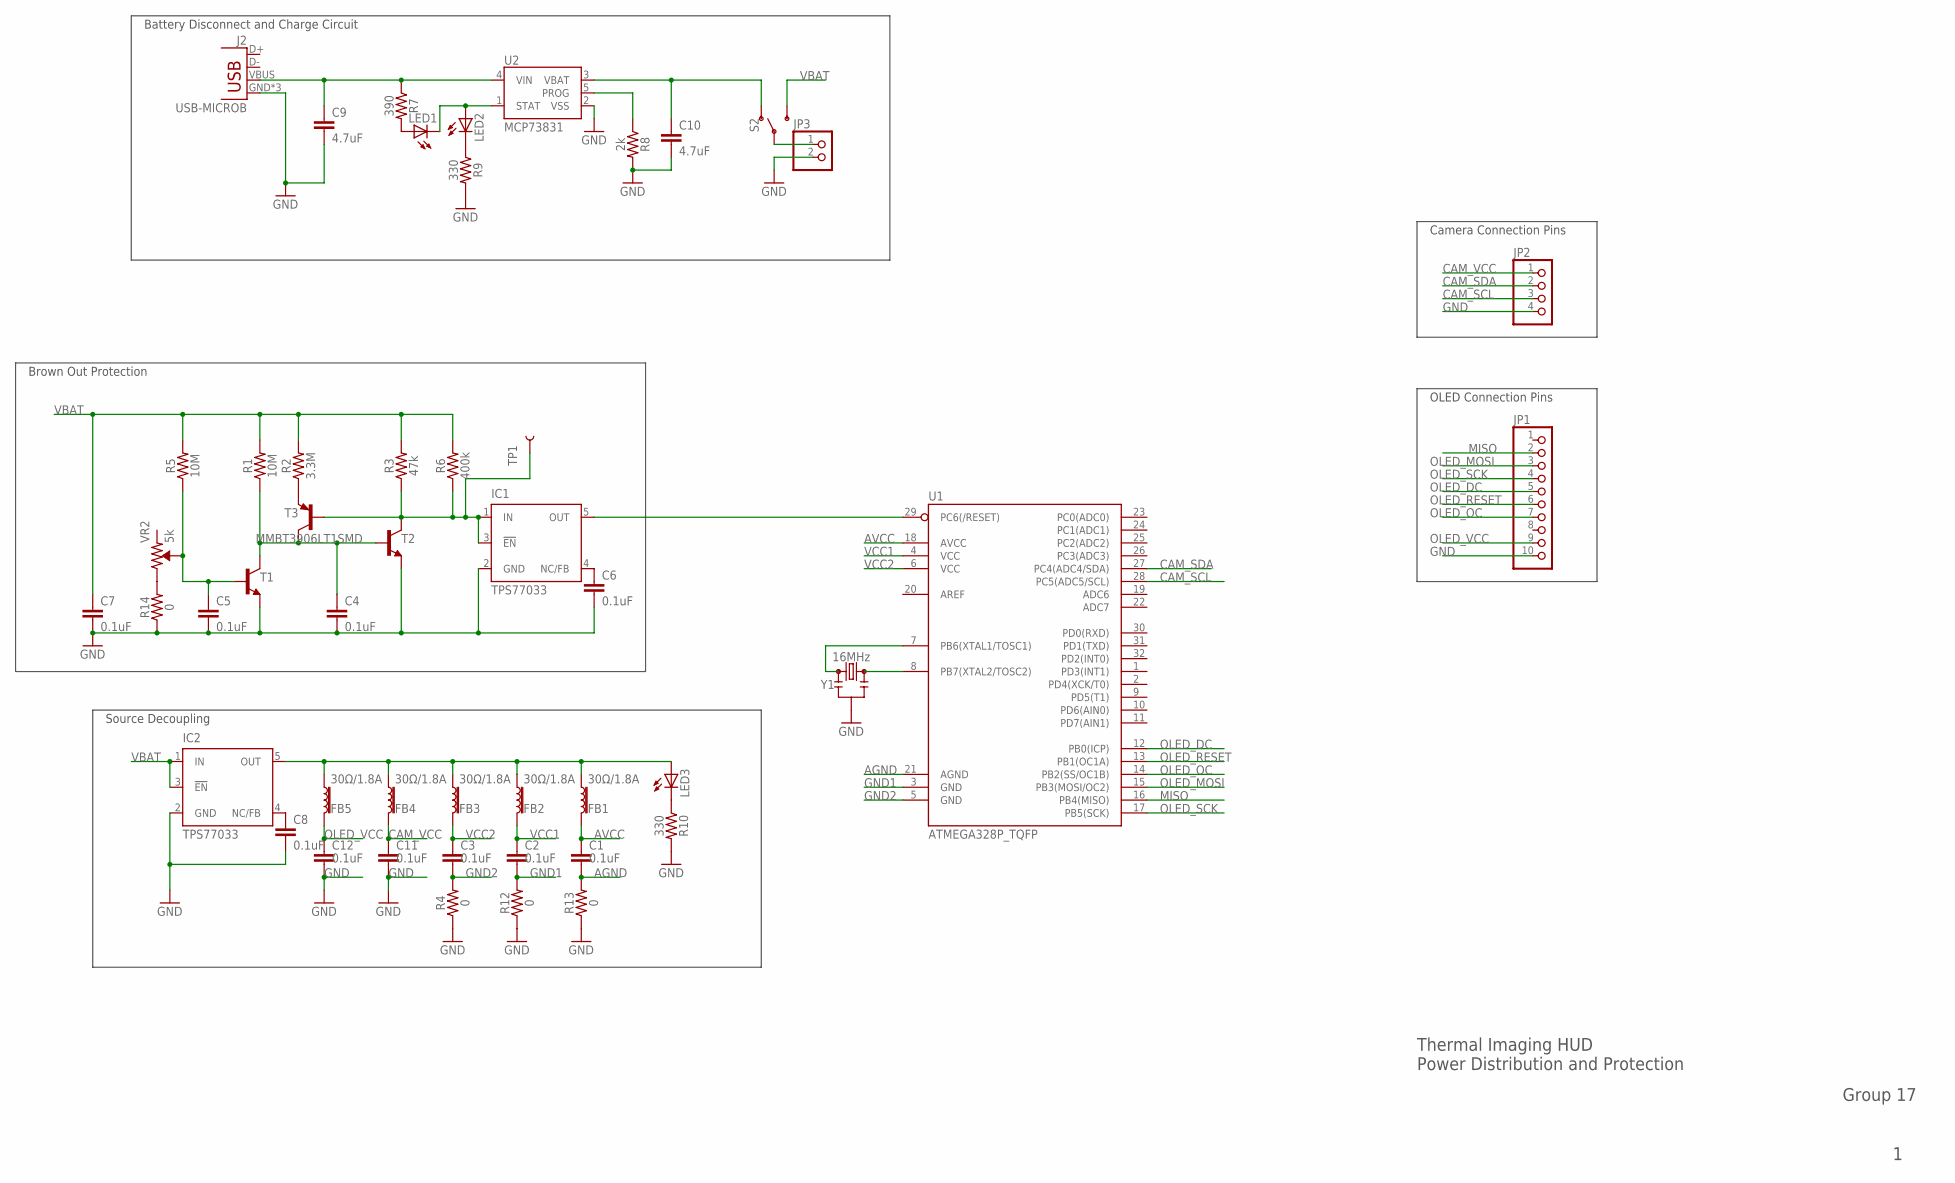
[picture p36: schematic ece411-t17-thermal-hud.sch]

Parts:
C1, C2, C3, C4, C5, C6, C7, C8, C11, C12: 0.1uF; 0603
C9, C10: 4.7uF; 0603
FB1, FB2, FB3, FB4, FB5: 30Ω/1.8A; 0603
IC1, IC2: TPS77033; SOT23-DBV
J2: USB-MICROB
JP1: PINHD-1X10/90; 1X10/90
JP2: PINHD-1X4/90; 1X04/90
JP3: PINHD-1X2/90; 1X02/90
LED1, LED2, LED3: LEDCHIPLED_0603; CHIPLED_0603
R1, R5: 10M; 0603
R2: 3.3M; 0603
R3: 47k; 0603
R4, R12, R13, R14: 0; 0603
R6: 400k; 0603
R7: 390; 0603
R8: 2k; 0603
R9, R10: 330; 0603
S2: SWITCH-SPDT-PTH-11.6X4.0MM; SWITCH_SPDT_PTH_11.6X4.0MM
T1, T2: MMBT3904LT1-NPN-SOT23-BEC; SOT23-BEC
T3: MMBT3906LT1SMD; SOT23-BEC
TP1: TEST-POINT3X5; PAD.03X.05
U1: ATMEGA328P_TQFP; TQFP32-08
U2: MCP73831; SOT23-5
VR2: 5k; TRIMPOT-SMD-5MM
Y1: 16MHz; RESONATOR-SMD-3.2X1.3

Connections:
AGND: C1.2, R13.2, U1.21 (AGND)
AVCC: C1.1, FB1.2, U1.18 (AVCC)
CAM_SCL: JP2.3, U1.28 (PC5(ADC5/SCL))
CAM_SDA: JP2.2, U1.27 (PC4(ADC4/SDA))
CAM_VCC: C11.1, FB4.2, JP2.1
GND: C4.2, C5.2, C6.2, C7.2, C8.2, C9.2, C10.2, C11.2, C12.2, IC1.2 (GND), IC2.2 (GND), J2.GND, J2.MT1 (GND), J2.MT2 (GND), JP1.10, JP2.4, JP3.2, R4.1, R8.2, R9.2, R10.2, R12.1, R13.1, R14.1, T1.E, T2.E, U2.2 (VSS), Y1.2
GND1: C2.2, R12.2, U1.3 (GND)
GND2: C3.2, R4.2, U1.5 (GND)
LIPO_POS: JP3.1, S2.2
MISO: JP1.2, U1.16 (PB4(MISO))
unnamed: IC1.1 (IN), IC1.3 (!EN), R3.1, R6.1, T2.C, T3.B, TP1.P$1
unnamed: C5.1, R5.1, T1.B, VR2.B (WIPER)
unnamed: IC1.5 (OUT), U1.29 (PC6(/RESET))
unnamed: C4.1, R1.1, T1.C, T2.B, T3.C
unnamed: R2.1, T3.E
unnamed: LED1.C, LED2.A, U2.1 (STAT)
unnamed: C6.1, IC1.4 (NC/FB)
unnamed: FB1.1, FB2.1, FB3.1, FB4.1, FB5.1, IC2.5 (OUT), LED3.A
unnamed: C8.1, IC2.4 (NC/FB)
unnamed: LED1.A, R7.2
unnamed: C9.1, J2.VBUS, R7.1, U2.4 (VIN)
unnamed: R8.1, U2.5 (PROG)
unnamed: C10.1, S2.1 (O), U2.3 (VBAT)
unnamed: R14.2, VR2.C (CW)
unnamed: U1.7 (PB6(XTAL1/TOSC1)), Y1.1
unnamed: U1.8 (PB7(XTAL2/TOSC2)), Y1.3
unnamed: LED2.C, R9.1
unnamed: LED3.C, R10.1
OLED_DC: JP1.5, U1.12 (PB0(ICP))
OLED_MOSI: JP1.3, U1.15 (PB3(MOSI/OC2))
OLED_OC: JP1.7, U1.14 (PB2(SS/OC1B))
OLED_RESET: JP1.6, U1.13 (PB1(OC1A))
OLED_SCK: JP1.4, U1.17 (PB5(SCK))
OLED_VCC: C12.1, FB5.2, JP1.9
VBAT: C7.1, IC2.1 (IN), IC2.3 (!EN), R1.2, R2.2, R3.2, R5.2, R6.2, S2.3 (S)
VCC1: C2.1, FB2.2, U1.4 (VCC)
VCC2: C3.1, FB3.2, U1.6 (VCC)

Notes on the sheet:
Battery Disconnect and Charge Circuit
Brown Out Protection
Source Decoupling
Camera Connection Pins
OLED Connection Pins
Group 17
Thermal Imaging HUD Power Distribution and Protection

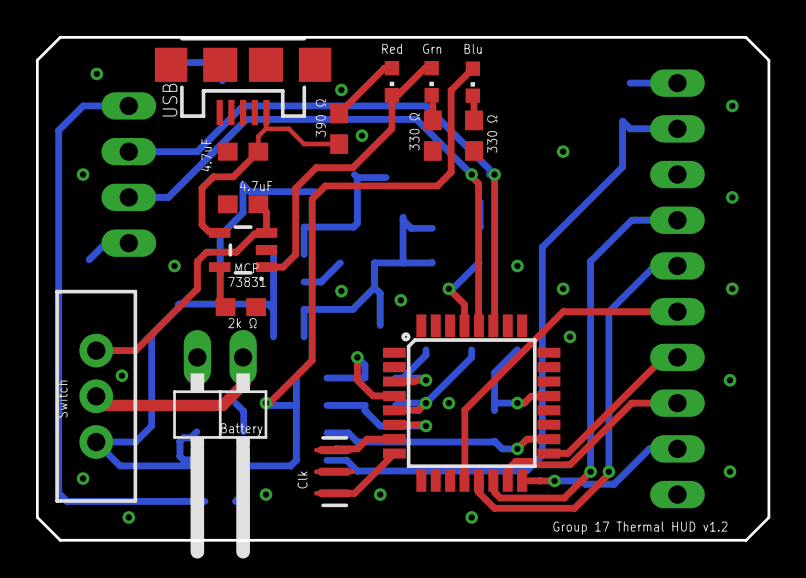
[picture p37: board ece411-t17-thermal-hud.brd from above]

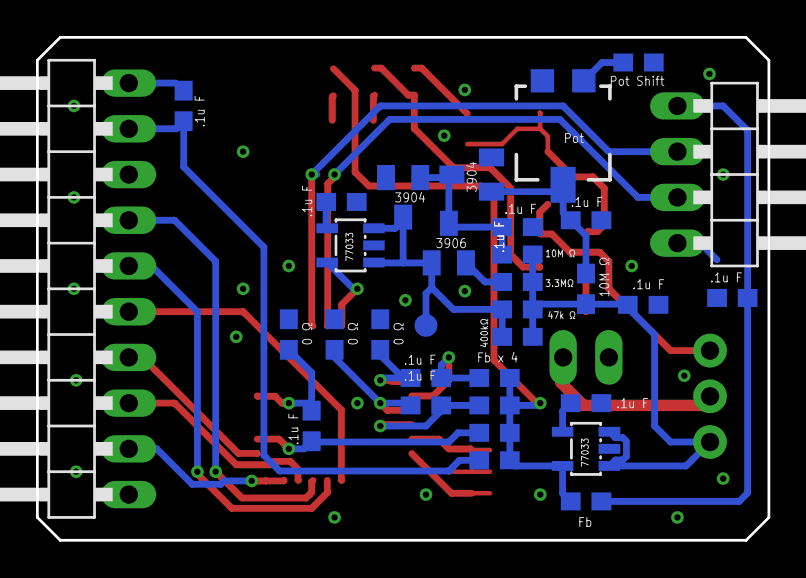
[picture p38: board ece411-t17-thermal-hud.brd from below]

Board: 2 copper layers, 40.6 x 27.9 mm, 48 parts (33 on the bottom side), 37 nets.

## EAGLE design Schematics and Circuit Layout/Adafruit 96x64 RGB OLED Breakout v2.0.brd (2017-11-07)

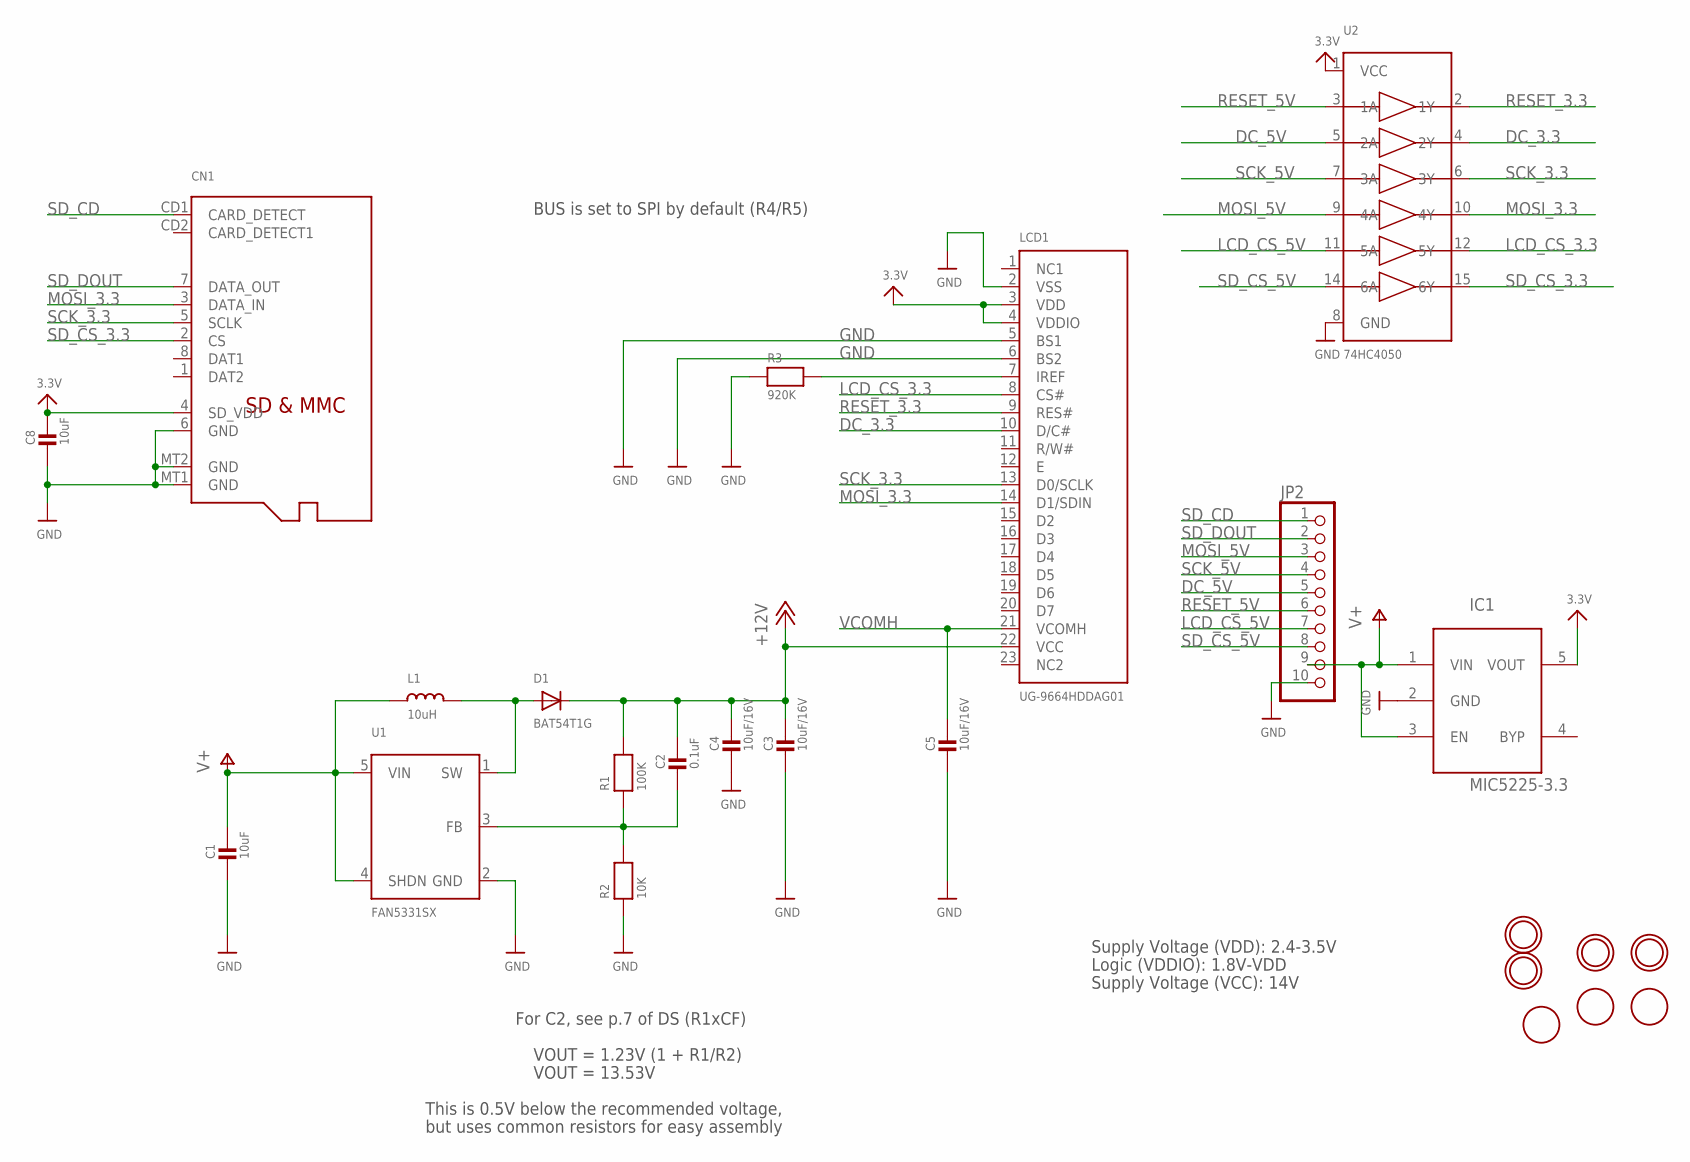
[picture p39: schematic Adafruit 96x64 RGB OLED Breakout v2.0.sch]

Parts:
C1, C8: 10uF; 0805
C2: 0.1uF; 0805
C3, C4, C5: 10uF/16V; 0805
CN1: MICROSD
D1: BAT54T1G; SOD-123
IC1: MIC5225-3.3; SOT23-5L
JP2: HEADER-1X10THICKER; 1X10_ROUND_76
L1: 10uH; INDUCTOR_1007
LCD1: UG-9664HDDAG01; UG-9664HDDAG01_WRAPAROUND
R1: 100K; 0805
R2: 10K; 0805
R3: 920K; 0805
U1: FAN5331SX; SOT23-5
U2: 74HC4050; SOIC16
U$9, U$10, U$11, U$15: MOUNTINGHOLE2.5; MOUNTINGHOLE_2.5_PLATED
U$12, U$13, U$16: FIDUCIAL; FIDUCIAL_1MM

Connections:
3.3V: C8.1, CN1.4 (SD_VDD), IC1.5 (VOUT), LCD1.3 (VDD), LCD1.4 (VDDIO), U2.1 (VCC)
+12V: C2.1, C3.1, C4.1, D1.C, LCD1.22 (VCC), R1.2
DC_3.3: LCD1.10 (D/C#), U2.4 (2Y)
DC_5V: JP2.5, U2.5 (2A)
GND: C1.2, C3.2, C4.2, C5.2, C8.2, CN1.6 (GND), CN1.MT1 (GND), CN1.MT2 (GND), IC1.2 (GND), JP2.10, LCD1.2 (VSS), LCD1.5 (BS1), LCD1.6 (BS2), R2.1, R3.1, U1.2 (GND), U2.8 (GND)
LCD_CS_3.3: LCD1.8 (CS#), U2.12 (5Y)
LCD_CS_5V: JP2.7, U2.11 (5A)
MOSI_3.3: CN1.3 (DATA_IN), LCD1.14 (D1/SDIN), U2.10 (4Y)
MOSI_5V: JP2.3, U2.9 (4A)
unnamed: D1.A, L1.P$2 (2), U1.1 (SW)
unnamed: C2.2, R1.1, R2.2, U1.3 (FB)
unnamed: LCD1.7 (IREF), R3.2
RESET_3.3: LCD1.9 (RES#), U2.2 (1Y)
RESET_5V: JP2.6, U2.3 (1A)
SCK_3.3: CN1.5 (SCLK), LCD1.13 (D0/SCLK), U2.6 (3Y)
SCK_5V: JP2.4, U2.7 (3A)
SD_CD: CN1.CD1 (CARD_DETECT), JP2.1
SD_CS_3.3: CN1.2 (CS), U2.15 (6Y)
SD_CS_5V: JP2.8, U2.14 (6A)
SD_DOUT: CN1.7 (DATA_OUT), JP2.2
V+: C1.1, IC1.1 (VIN), IC1.3 (EN), JP2.9, L1.P$1 (1), U1.4 (SHDN), U1.5 (VIN)
VCOMH: C5.1, LCD1.21 (VCOMH)

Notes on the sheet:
Supply Voltage (VDD): 2.4-3.5V
Logic (VDDIO): 1.8V-VDD
Supply Voltage (VCC): 14V
For C2, see p.7 of DS (R1xCF)
VOUT = 1.23V (1 + R1/R2)
VOUT = 13.53V
This is 0.5V below the recommended voltage,
but uses common resistors for easy assembly
BUS is set to SPI by default (R4/R5)

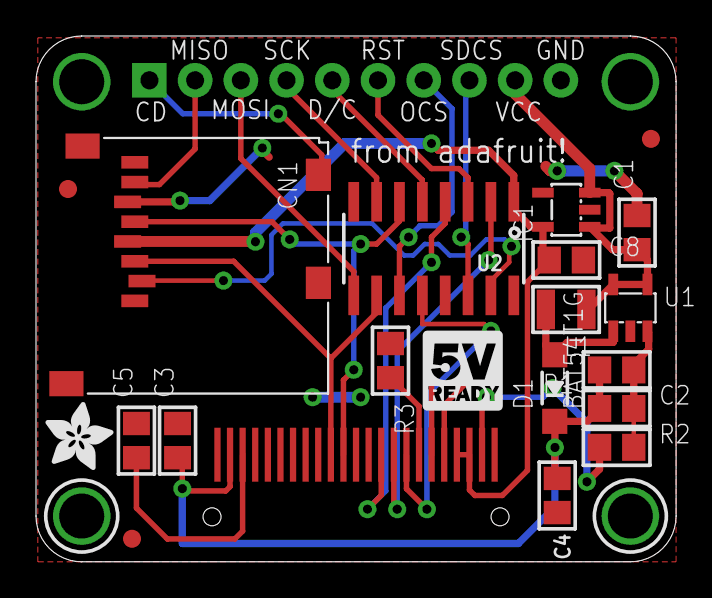
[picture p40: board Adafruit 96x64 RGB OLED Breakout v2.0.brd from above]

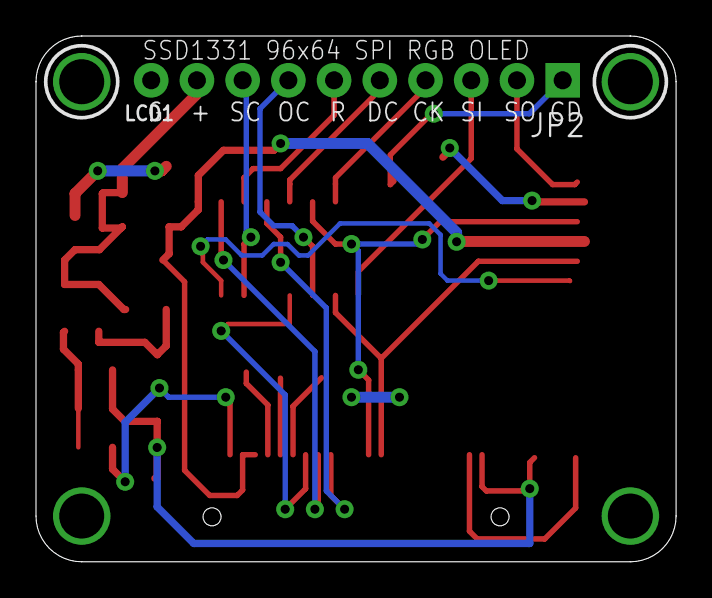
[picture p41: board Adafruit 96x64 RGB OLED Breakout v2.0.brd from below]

Board: 2 copper layers, 35.6 x 29.2 mm, 26 parts (4 on the bottom side), 22 nets.

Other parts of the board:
U$17: ADAFRUIT_3.5MM
U$28: LOGIC_5VREADY_5MM

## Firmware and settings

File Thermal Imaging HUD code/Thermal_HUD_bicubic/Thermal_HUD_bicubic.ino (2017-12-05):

/***************************************************
  This is a example sketch demonstrating the graphics
  capabilities of the SSD1331 library  for the 0.96"
  16-bit Color OLED with SSD1331 driver chip
  Pick one up today in the adafruit shop!
  ------> http://www.adafruit.com/products/684
  These displays use SPI to communicate, 4 or 5 pins are required to
  interface
  Adafruit invests time and resources providing this open source code,
  please support Adafruit and open-source hardware by purchasing
  products from Adafruit!
  Written by Limor Fried/Ladyada for Adafruit Industries.
  BSD license, all text above must be included in any redistribution
****************************************************/


/***************************************************************************
  This is a library for the AMG88xx GridEYE 8x8 IR camera

  This sketch tries to read the pixels from the sensor

  Designed specifically to work with the Adafruit AMG88 breakout
  ----> http://www.adafruit.com/products/3538

  These sensors use I2C to communicate. The device's I2C address is 0x69

  Adafruit invests time and resources providing this open source code,
  please support Adafruit andopen-source hardware by purchasing products
  from Adafruit!

  Written by Dean Miller for Adafruit Industries.
  BSD license, all text above must be included in any redistribution
***************************************************************************/

#include <Adafruit_GFX.h>
#include <Adafruit_SSD1331.h>
#include <SPI.h>
#include <Wire.h>
#include <Adafruit_AMG88xx.h>

// see if a bit code x86 proc code cant be used to create an array of defines or a #defined array, ie get colors to take up flash not dynamic
const uint16_t colors[] = {
  0x0000, 0x0801, 0x1002, 0x1803, 0x2004, 0x2805, 0x3006, 0x3807, 0x4008, 0x4809,
  0x500A, 0x580B, 0x600C, 0x580C, 0x500C, 0x480C, 0x400C, 0x380C, 0x300C, 0x280C,
  0x200C, 0x180C, 0x100C, 0x080C, 0x000C, 0x000D, 0x000E, 0x000F, 0x0010, 0x0011,
  0x0012, 0x0013, 0x0014, 0x0015, 0x0016, 0x0017, 0x0018, 0x0019, 0x001A, 0x001B,
  0x001C, 0x001D, 0x001E, 0x001F, 0x003F, 0x007F, 0x009F, 0x00DF, 0x00FF, 0x013F,
  0x015F, 0x019F, 0x01BF, 0x01FF, 0x021F, 0x025F, 0x027F, 0x02BF, 0x02DF, 0x031F,
  0x033F, 0x037F, 0x039F, 0x03FF, 0x045F, 0x051F, 0x057F, 0x05DF, 0x063F, 0x069F,
  0x06FF, 0x075F, 0x07BF, 0x07FF, 0x07FE, 0x07FC, 0x07FB, 0x07F9, 0x07F8, 0x07F6,
  0x07F5, 0x07F3, 0x07F2, 0x07F0, 0x07EF, 0x07ED, 0x07EC, 0x07EA, 0x07E9, 0x07E7,
  0x07E6, 0x07E4, 0x07E3, 0x07E1, 0x07E0, 0x0FE0, 0x1FE0, 0x27E0, 0x37E0, 0x3FE0,
  0x4FE0, 0x57E0, 0x67E0, 0x6FE0, 0x7FE0, 0x87E0, 0x97E0, 0x9FE0, 0xAFE0, 0xB7E0,
  0xC7E0, 0xCFE0, 0xDFE0, 0xE7E0, 0xF7E0, 0xFFE0, 0xFF80, 0xFF20, 0xFEC0, 0xFE60,
  0xFE00, 0xFDA0, 0xFD40, 0xFCE0, 0xFC80, 0xFC20, 0xFBC0, 0xFB60, 0xFB00, 0xFAA0,
  0xFA40, 0xF9E0, 0xF980, 0xF920, 0xF8C0, 0xF860, 0xF800, 0xF820, 0xF841, 0xF861,
  0xF8A2, 0xF8C3, 0xF8E3, 0xF904, 0xF945, 0xF965, 0xF986, 0xF9A6, 0xF9E7, 0xFA08,
  0xFA28, 0xFA49, 0xFA8A, 0xFAAA, 0xFACB, 0xFAEB, 0xFB2C, 0xFB4D, 0xFB6D, 0xFB8E,
  0xFBCF, 0xFBEF, 0xFC10, 0xFC30, 0xFC71, 0xFCD3, 0xFD14, 0xFD34, 0xFD55, 0xFD75,
  0xFDB6, 0xFDD7, 0xFDF7, 0xFE18, 0xFE59, 0xFE79, 0xFE9A, 0xFEBA, 0xFEFB, 0xFF1C,
  0xFF3C, 0xFF5D, 0xFF9E, 0xFFBE, 0xFFDF, 0xFFFF,
};

#define AMG_COLS 8
#define AMG_ROWS 8
#define INTERPOLATED_COLS 16
#define INTERPOLATED_ROWS 16
#define MINTEMP -20     //low range of the sensor (this will be blue on the screen)
#define MAXTEMP 80      //high range of the sensor (this will be red on the screen)
#define XOFF 40
#define YOFF 24

// You can use any (4 or) 5 pins
#define sclk 13
#define mosi 11
#define cs   10
#define rset 9
#define dc   8

// Color definitions
#define BLACK           0x0000
#define BLUE            0x001F
#define RED             0xF800
#define WHITE           0xFFFF

uint8_t get_point(int8_t *p, uint8_t rows, uint8_t cols, int8_t x, int8_t y);
void set_point(uint8_t *p, uint8_t rows, uint8_t cols, int8_t x, int8_t y, float f);
void get_adjacents_2d(int8_t *src, float *dest, uint8_t rows, uint8_t cols, int8_t x, int8_t y);
float cubicInterpolate(float p[], float x);
float bicubicInterpolate(float p[], float x, float y);
void interpolate_image(uint8_t *src, uint8_t src_rows, uint8_t src_cols,
                       uint8_t *dest, uint8_t dest_rows, uint8_t dest_cols);

int8_t pixels[AMG_COLS * AMG_ROWS];
Adafruit_AMG88xx amg;
unsigned long delayTime;
Adafruit_SSD1331 display = Adafruit_SSD1331(cs, dc, mosi, sclk, rset);

void setup(void) {
  Serial.begin(9600);
  display.begin();

  Serial.println("init");
  display.fillScreen(BLACK);

  char* text = "if u can read this you dont need glasses";
  testdrawtext(text, WHITE);

  display.fillScreen(BLACK);

  // optimized lines
  testfastlines(RED, BLUE);
  delay(500);

  testtriangles();

  delay(500);

  bool status;

  // default settings
  status = amg.begin();

  if (!status)
  {
    //Serial.println("Could not find a valid AMG88xx sensor, check wiring!");
    while (1)
    {
      display.fillScreen(RED);
      delay(1000);
      display.fillScreen(BLACK);
      delay(1000);
    }
  }
  display.fillScreen(BLACK);
  delay(1000);

  //for (int i = 165; i < 170; i++)
  //{
    //Serial.println(colors[i], HEX);
    //display.fillScreen(colors[i]);
  //}

  //for (int i = 0; i < 200; i++)
  //{
    //display.fillScreen(colors[i]);
  //}

  Serial.println("done");
  delay(1000);
}

void loop() {
  //read all the pixels
  amg.readPixels(pixels);

  //Serial.print("[");
  //for(int i=1; i<=AMG88xx_PIXEL_ARRAY_SIZE; i++){
  //  Serial.print(pixels[i-1]);
  //  Serial.print(", ");
  //  if( i%8 == 0 ) Serial.println();
  //}
  //Serial.println("]");
  //Serial.println();  
  
  uint8_t dest_2d[INTERPOLATED_ROWS * INTERPOLATED_COLS];

  interpolate_image(pixels, AMG_ROWS, AMG_COLS, dest_2d, INTERPOLATED_ROWS, INTERPOLATED_COLS);

  //for (int i = 0; i < INTERPOLATED_ROWS; i++)
  //{
    //for (int j = 0; j < INTERPOLATED_COLS; j++)
    //{
      //Serial.print(dest_2d[i * INTERPOLATED_ROWS + j * INTERPOLATED_COLS]);
      //Serial.print(' ');
    //}
    //Serial.println("");
  //}

  drawpixels(dest_2d, INTERPOLATED_ROWS, INTERPOLATED_COLS);

  //delay(50);
}

/*---------------------------------------------------------
 * Function: drawpixels
 * Inputs:
 *      uint8_t *p:
 *      uint8_t rows:
 *      uint8_t cols:
 * Outputs:
 *      void (none)
 * Description:
 ---------------------------------------------------------*/
void drawpixels(uint8_t *p, uint8_t rows, uint8_t cols) {
  int colorTemp;
  for (int y = 0; y < rows; y++) {
    for (int x = 0; x < cols; x++) {
      uint8_t val = get_point(p, rows, cols, x, y);
      //if(val >= MAXTEMP) val = MAXTEMP;
      //else if(val <= MINTEMP) val = MINTEMP;
      
      //uint8_t colorIndex = map(val, MINTEMP, MAXTEMP, 40, 203);
      uint8_t colorIndex = 2*val + 41;
      display.drawPixel(y + YOFF, x + XOFF, colors[colorIndex]);
    }
  }
}

/*---------------------------------------------------------
 * Function: testdrawtext
 * Inputs:
 *      char *text:
 *      uint16_t color:
 * Outputs:
 *      void (none)
 * Description:
 ---------------------------------------------------------*/
void testdrawtext(char *text, uint16_t color)
{
  display.setTextSize(1);
  display.setTextColor(WHITE);
  display.setCursor(0, 0);

  for (uint8_t i = 0; i < 168; i++)
  {
    if (i == '\n')
    {
      continue;
    }
    display.write(i);
    if ((i > 0) && (i % 21 == 0))
    {
      display.println();
    }
  }
}

/*---------------------------------------------------------
 * Function: testfastlines
 * Inputs:
 *      uint16_t:
 *      uint16_t:
 * Outputs:
 *      void (none)
 * Description:
 ---------------------------------------------------------*/
void testfastlines(uint16_t color1, uint16_t color2)
{
  display.fillScreen(BLACK);
  for (int16_t y = 0; y < display.height() - 1; y += 5)
  {
    display.drawFastHLine(0, y, display.width() - 1, color1);
  }
  for (int16_t x = 0; x < display.width() - 1; x += 5)
  {
    display.drawFastVLine(x, 0, display.height() - 1, color2);
  }
}

/*---------------------------------------------------------
 * Function: testtriangles
 * Inputs:
 *      (none)
 * Outputs:
 *      (void)
 * Description:
 ---------------------------------------------------------*/
void testtriangles()
{
  display.fillScreen(BLACK);
  int color = 0xF800;
  int t;
  int w = display.width() / 2;
  int x = display.height();
  int y = 0;
  int z = display.width();
  for (t = 0; t <= 15; t += 1)
  {
    display.drawTriangle(w, y, y, x, z, x, color);
    x -= 4;
    y += 4;
    z -= 4;
    color += 100;
  }
}

/*---------------------------------------------------------
 * Function: get_point
 * Inputs:
 *      int8_t *p:
 *      uint8_t rows:
 *      uint8_t cols:
 *      uint8_t x:
 *      uint8_t y:
 * Outputs:
 *      uint8_t:
 * Description:
 ---------------------------------------------------------*/
uint8_t get_point(int8_t *p, uint8_t rows, uint8_t cols, int8_t x, int8_t y) {
  if (x < 0)        x = 0;
  if (y < 0)        y = 0;
  if (x >= cols)    x = cols - 1;
  if (y >= rows)    y = rows - 1;
  return p[y * cols + x];
}

/*---------------------------------------------------------
 * Function: set_point
 * Inputs:
 *      uint8_t *p:
 *      uint8_t rows:
 *      uint8_t cols:
 *      int8_t x:
 *      int8_t y:
 *      float f:
 * Outputs:
 *      void (none)
 * Description:
 ---------------------------------------------------------*/
void set_point(uint8_t *p, uint8_t rows, uint8_t cols, int8_t x, int8_t y, float f) {
  if ((x < 0) || (x >= cols)) return;
  if ((y < 0) || (y >= rows)) return;
  p[y * cols + x] = (uint8_t)f;
}

/*---------------------------------------------------------
 * Function: interpolate_image
 * Inputs:
 *      int8_t *src:
 *      uint8_t src_rows:
 *      uint8_t src_cols:
 *      uint8_t *dest:
 *      uint8_t dest_rows:
 *      uint8_t dest_cols:
 * Outputs:
 *      void (none)
 * Description:
 ---------------------------------------------------------*/
// src is a grid src_rows * src_cols
// dest is a pre-allocated grid, dest_rows*dest_cols
void interpolate_image(uint8_t *src, uint8_t src_rows, uint8_t src_cols, 
                       uint8_t *dest, uint8_t dest_rows, uint8_t dest_cols) {
  float mu_x = (src_cols - 1.0) / (dest_cols - 1.0);
  float mu_y = (src_rows - 1.0) / (dest_rows - 1.0);

  float adj_2d[16]; // matrix for storing adjacents
  
  for (uint8_t y_idx=0; y_idx < dest_rows; y_idx++) {
    for (uint8_t x_idx=0; x_idx < dest_cols; x_idx++) {
       float x = x_idx * mu_x;
       float y = y_idx * mu_y;
       //Serial.print("("); Serial.print(y_idx); Serial.print(", "); Serial.print(x_idx); Serial.print(") = ");
       //Serial.print("("); Serial.print(y); Serial.print(", "); Serial.print(x); Serial.print(") = ");
       get_adjacents_2d(src, adj_2d, src_rows, src_cols, x, y);
       
       //Serial.print("[");
       //for (uint8_t i=0; i<16; i++) {
         //Serial.print(adj_2d[i]); Serial.print(", ");
       //}
       //Serial.println("]");
       
       float frac_x = x - (int)x; // we only need the ~delta~ between the points
       float frac_y = y - (int)y; // we only need the ~delta~ between the points
       float out = bicubicInterpolate(adj_2d, frac_x, frac_y);
       //Serial.print("\tInterp: "); Serial.println(out);
       set_point(dest, dest_rows, dest_cols, x_idx, y_idx, out);
    }
  }
}

/*---------------------------------------------------------
 * Function: cubicInterpolate
 * Inputs:
 *      float p[]:
 *      float x:
 * Outputs:
 *      float:
 * Description:
 ---------------------------------------------------------*/
// p is a list of 4 points, 2 to the left, 2 to the right
float cubicInterpolate(float p[], float x) {
    float r = p[1] + (0.5 * x * (p[2] - p[0] + x*(2.0*p[0] - 5.0*p[1] + 4.0*p[2] - p[3] + x*(3.0*(p[1] - p[2]) + p[3] - p[0]))));
  /*
    Serial.print("interpolating: ["); 
    Serial.print(p[0],2); Serial.print(", ");
    Serial.print(p[1],2); Serial.print(", ");
    Serial.print(p[2],2); Serial.print(", ");
    Serial.print(p[3],2); Serial.print("] w/"); Serial.print(x); Serial.print(" = ");
    Serial.println(r);
  */
    return r;
}

/*---------------------------------------------------------
 * Function: bicubicInterpolate
 * Inputs:
 *      float p[]:
 *      float x:
 *      float y:
 * Outputs:
 *      float:
 * Description:
 ---------------------------------------------------------*/
// p is a 16-point 4x4 array of the 2 rows & columns left/right/above/below
float bicubicInterpolate(float p[], float x, float y) {
    float arr[4] = {0,0,0,0};
    arr[0] = cubicInterpolate(p+0, x);
    arr[1] = cubicInterpolate(p+4, x);
    arr[2] = cubicInterpolate(p+8, x);
    arr[3] = cubicInterpolate(p+12, x);
    return cubicInterpolate(arr, y);
}

/*---------------------------------------------------------
 * Function: get_adjacent_2d
 * Inputs:
 *      int8_t *src:
 *      float *dest:
 *      uint8_t rows:
 *      uint8_t cols:
 *      int8_t x:
 *      int8_t y:
 * Outputs:
 *      void (none)
 * Description:
 ---------------------------------------------------------*/
// src is rows*cols and dest is a 16-point array passed in already allocated!
void get_adjacents_2d(int8_t *src, float *dest, uint8_t rows, uint8_t cols, int8_t x, int8_t y) {
    Serial.print("("); Serial.print(x); Serial.print(", "); Serial.print(y); Serial.println(")");
    float arr[4];
    for (int8_t delta_y = -1; delta_y < 3; delta_y++) { // -1, 0, 1, 2
        float *row = dest + 4 * (delta_y+1); // index into each chunk of 4
        for (int8_t delta_x = -1; delta_x < 3; delta_x++) { // -1, 0, 1, 2
            row[delta_x+1] = get_point(src, rows, cols, x+delta_x, y+delta_y);
        }
    }
}

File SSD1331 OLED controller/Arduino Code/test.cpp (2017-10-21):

/*************************************************** 
  This is a example sketch demonstrating the graphics
  capabilities of the SSD1331 library  for the 0.96" 
  16-bit Color OLED with SSD1331 driver chip
  Pick one up today in the adafruit shop!
  ------> http://www.adafruit.com/products/684
  These displays use SPI to communicate, 4 or 5 pins are required to  
  interface
  Adafruit invests time and resources providing this open source code, 
  please support Adafruit and open-source hardware by purchasing 
  products from Adafruit!
  Written by Limor Fried/Ladyada for Adafruit Industries.  
  BSD license, all text above must be included in any redistribution
 ****************************************************/


// You can use any (4 or) 5 pins 
#define sclk 13
#define mosi 11
#define cs   10
#define rst  9
#define dc   8


// Color definitions
#define	BLACK           0x0000
#define	BLUE            0x001F
#define	RED             0xF800
#define	GREEN           0x07E0
#define CYAN            0x07FF
#define MAGENTA         0xF81F
#define YELLOW          0xFFE0  
#define WHITE           0xFFFF

#include <Adafruit_GFX.h>
#include <Adafruit_SSD1331.h>
#include <SPI.h>

// Option 1: use any pins but a little slower
Adafruit_SSD1331 display = Adafruit_SSD1331(cs, dc, mosi, sclk, rst);  

// Option 2: must use the hardware SPI pins 
// (for UNO thats sclk = 13 and sid = 11) and pin 10 must be 
// an output. This is much faster - also required if you want
// to use the microSD card (see the image drawing example)
//Adafruit_SSD1331 display = Adafruit_SSD1331(cs, dc, rst);

float p = 3.1415926;

void setup(void) {
  Serial.begin(9600);
  Serial.print("hello!");
  display.begin();

  Serial.println("init");
  uint16_t time = millis();
  display.fillScreen(BLACK);
  time = millis() - time;
  
  Serial.println(time, DEC);
  delay(500);
   
  lcdTestPattern();
  delay(1000);
  
  display.fillScreen(BLACK);
  display.setCursor(0,0);
  display.print("Lorem ipsum dolor sit amet, consectetur adipiscing elit. Curabitur adipiscing ante sed nibh tincidunt feugiat. Maecenas enim massa");
  delay(1000);

  // tft print function!
  tftPrintTest();
  delay(2000);
  
  //a single pixel
  display.drawPixel(display.width()/2, display.height()/2, GREEN);
  delay(500);
  
  // line draw test
  testlines(YELLOW);
  delay(500);    
  
  // optimized lines
  testfastlines(RED, BLUE);
  delay(500);    
 
  testdrawrects(GREEN);
  delay(1000);

  testfillrects(YELLOW, MAGENTA);
  delay(1000);

  display.fillScreen(BLACK);
  testfillcircles(10, BLUE);
  testdrawcircles(10, WHITE);
  delay(1000);

  testroundrects();
  delay(500);
  
  testtriangles();
  delay(500);
  
  Serial.println("done");
  delay(1000);
}

void loop() {
}

void testlines(uint16_t color) {
   display.fillScreen(BLACK);
   for (int16_t x=0; x < display.width()-1; x+=6) {
     display.drawLine(0, 0, x, display.height()-1, color);
   }
   for (int16_t y=0; y < display.height()-1; y+=6) {
     display.drawLine(0, 0, display.width()-1, y, color);
   }
   
   display.fillScreen(BLACK);
   for (int16_t x=0; x < display.width()-1; x+=6) {
     display.drawLine(display.width()-1, 0, x, display.height()-1, color);
   }
   for (int16_t y=0; y < display.height()-1; y+=6) {
     display.drawLine(display.width()-1, 0, 0, y, color);
   }
   
   display.fillScreen(BLACK);
   for (int16_t x=0; x < display.width()-1; x+=6) {
     display.drawLine(0, display.height()-1, x, 0, color);
   }
   for (int16_t y=0; y < display.height()-1; y+=6) {
     display.drawLine(0, display.height()-1, display.width()-1, y, color);
   }

   display.fillScreen(BLACK);
   for (int16_t x=0; x < display.width()-1; x+=6) {
     display.drawLine(display.width()-1, display.height()-1, x, 0, color);
   }
   for (int16_t y=0; y < display.height()-1; y+=6) {
     display.drawLine(display.width()-1, display.height()-1, 0, y, color);
   }
   
}

void testdrawtext(char *text, uint16_t color) {
  display.setTextSize(1);
  display.setTextColor(WHITE);
  display.setCursor(0,0);

  for (uint8_t i=0; i < 168; i++) {
    if (i == '\n') continue;
    display.write(i);
    if ((i > 0) && (i % 21 == 0))
      display.println();
  }    
}

void testfastlines(uint16_t color1, uint16_t color2) {
   display.fillScreen(BLACK);
   for (int16_t y=0; y < display.height()-1; y+=5) {
     display.drawFastHLine(0, y, display.width()-1, color1);
   }
   for (int16_t x=0; x < display.width()-1; x+=5) {
     display.drawFastVLine(x, 0, display.height()-1, color2);
   }
}

void testdrawrects(uint16_t color) {
 display.fillScreen(BLACK);
 for (int16_t x=0; x < display.height()-1; x+=6) {
   display.drawRect((display.width()-1)/2 -x/2, (display.height()-1)/2 -x/2 , x, x, color);
 }
}

void testfillrects(uint16_t color1, uint16_t color2) {
 display.fillScreen(BLACK);
 for (int16_t x=display.height()-1; x > 6; x-=6) {
   display.fillRect((display.width()-1)/2 -x/2, (display.height()-1)/2 -x/2 , x, x, color1);
   display.drawRect((display.width()-1)/2 -x/2, (display.height()-1)/2 -x/2 , x, x, color2);
 }
}

void testfillcircles(uint8_t radius, uint16_t color) {
  for (uint8_t x=radius; x < display.width()-1; x+=radius*2) {
    for (uint8_t y=radius; y < display.height()-1; y+=radius*2) {
      display.fillCircle(x, y, radius, color);
    }
  }  
}

void testdrawcircles(uint8_t radius, uint16_t color) {
  for (int16_t x=0; x < display.width()-1+radius; x+=radius*2) {
    for (int16_t y=0; y < display.height()-1+radius; y+=radius*2) {
      display.drawCircle(x, y, radius, color);
    }
  }  
}

void testtriangles() {
  display.fillScreen(BLACK);
  int color = 0xF800;
  int t;
  int w = display.width()/2;
  int x = display.height();
  int y = 0;
  int z = display.width();
  for(t = 0 ; t <= 15; t+=1) {
    display.drawTriangle(w, y, y, x, z, x, color);
    x-=4;
    y+=4;
    z-=4;
    color+=100;
  }
}

void testroundrects() {
  display.fillScreen(BLACK);
  int color = 100;
  int i;
  int t;
  for(t = 0 ; t <= 4; t+=1) {
  int x = 0;
  int y = 0;
  int w = display.width();
  int h = display.height();
    for(i = 0 ; i <= 24; i+=1) {
    display.drawRoundRect(x, y, w, h, 5, color);
    x+=2;
    y+=3;
    w-=4;
    h-=6;
    color+=1100;
  }
  color+=100;
  }
}
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

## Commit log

2017-10-20 Adafruit AMG8833 Thermal Camera Sensor Documentation
    Documentation for the Adafruit AMG8833 8x8 Thermal Camera Sensor that covers pinouts, wiring, testing, use and code libraries
2017-10-20 AMG88XX Technical Reference
    Technical Reference Document for the AMG88XX Infrared Array Sensor known as "Grid-EYE". Documentation contains characteristics, schematic and interfacing/use information for the AMG88XX
2017-10-20 OLED Datasheet
    Technical reference document for the 96x64 RGB Dot Matrix OLED screen used in the design. Document contains design specifications and information on the SSD1331 Driver that is used by the device and 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
2017-10-21 Create Arduino_PixelTest
    AMG8833 GridEYE 8x8 IR camera
2017-10-21 Test code for the SSD1331 using Arduino
    This code for a proof of concept using the SSD1331
2017-10-21 Moved the Arduino test code for SSD1331
2017-10-21 File was moved to Arduino code folder
2017-10-21 Arduino cpp for proof of concept for AMG8833
2017-10-21 Create sch file for AMG8833
    [AMG8833_REV-B.sch]
2017-10-21 Create a brd file for the AMG8833
    [AMG8833_REV-B.brd]
2017-10-21 Create brd file for OLED screen
    [Adafruit TFT144 Breakout Rev B.brd]
2017-10-21 Create sch file for the OLED screen
    [Adafruit TFT144 Breakout Rev B.sch]
2017-10-26 Power and charging systems
    [Controller.sch]
2017-11-02 final Schematic
    [Controller.brd]
2017-11-03 Delete atmega328-tqfp-arduino-pinout.jpg
    removed in order to relocate and clean up main page
2017-11-05 Adafruit OLED Breakout board file
    [Adafruit 96x64 RGB OLED Breakout v2.0.brd]
2017-11-05 Adafruit OLED breakout schematic file
    [Adafruit 96x64 RGB OLED Breakout v2.0.sch]
2017-11-05 Wrong board file
    [Adafruit TFT144 Breakout Rev B.brd]
2017-11-05 Wrong schematic file
    [Adafruit TFT144 Breakout Rev B.sch]
2017-11-07 Pre Layout
    [Controller.brd, Controller.sch]
2017-11-10 altered board to fit OSH DRS
    [Controller.brd, Controller.sch]
2017-11-13 Prototype Structure
    [Controller back mount.brd, Controller back mount.sch, optical body.SLDPRT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]
2017-11-14 Tried to fix errors to thermal HUD code
    The fixs applied fixed some of the errors, but more still need to be
    fixed.
    [Thermal_HUD_bicubic.ino]
2017-11-14 Cut unused functions from AMG88xx.cpp
    Functions that are not used by the readPixel function. The read pixel function is the only function being called by our main program file.
2017-11-14 Cut unused functions from the AMG88xx.h
    Removed unused function prototypes from the header file to reflect changes made to AMG88xx.cpp file.
2017-11-15 Delete Thermal_HUD_bicubic.ino
    Odd merge issues leading to compilation errors
    [Thermal_HUD_bicubic.ino]
2017-11-16 Osh subit
    [ece411-t17-thermal-hud.brd, ece411-t17-thermal-hud.sch]
2017-11-20 reorganized and added Test Sheet
    [AMG8833_REV-B.brd, AMG8833_REV-B.sch, Adafruit 96x64 RGB OLED Breakout v2.0.brd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]
2017-11-28 Cut unused functions and added function definition
2017-11-30 Adjusted Structural Files
    [optical body_v1.2.SLDPRT, optical body_v1.2.STL]
2017-12-01 test case update
2017-12-06 Added the bill of materials

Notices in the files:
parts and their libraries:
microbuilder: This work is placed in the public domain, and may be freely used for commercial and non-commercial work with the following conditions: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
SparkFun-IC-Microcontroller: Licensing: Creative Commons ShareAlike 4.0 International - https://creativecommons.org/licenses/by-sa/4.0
